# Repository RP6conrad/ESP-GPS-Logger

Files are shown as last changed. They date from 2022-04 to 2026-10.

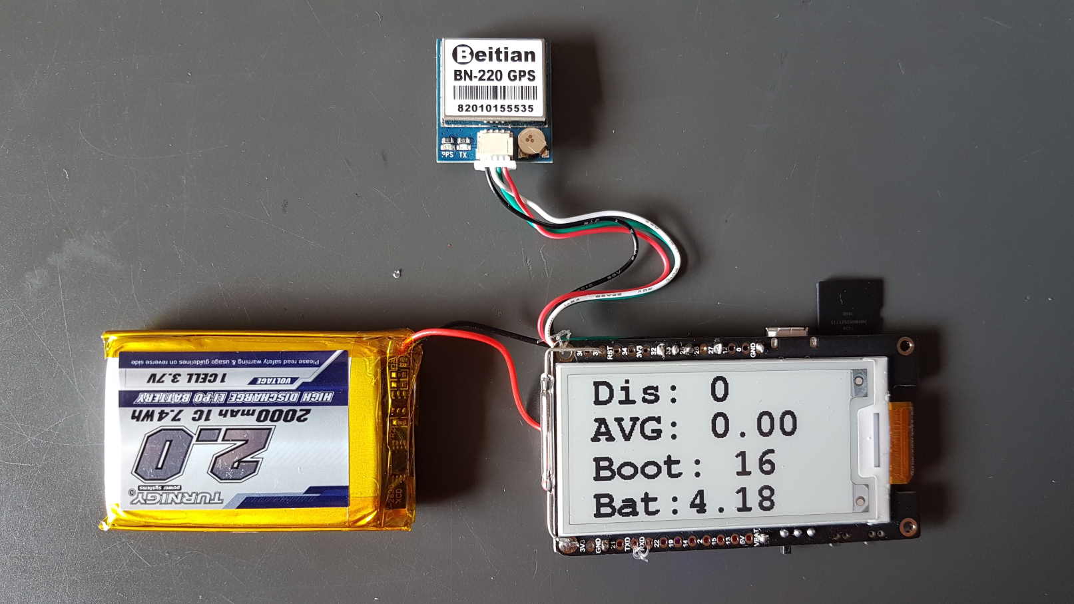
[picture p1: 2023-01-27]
Doc/ESP-naked.jpg

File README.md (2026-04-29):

# ESP-GPS logger

GPS logger for Speedsurfing, based on ESP32 & Ublox  hardware.  This is a open source project for a gps-speedlogger with a ESP32 µ-controller. This logger is approved for uploading to [http://gps-speedsurfing.com](http://gps-speedsurfing.com)
ESP GPS banner 1024x500

#### Hardware :
- e-paper display with build in ESP32 and micro SD-card(lilygo ttgo T5).
- A gps module ublox M8n / M9 / M10 is connected over serial. 
- A 2000 mAh protected lipo (103450) 
- Inductive charging coil
- Watersealed housing, electrical box or GoPro housing
#### Software
- GPS is configured for sending ubx navpvt (+navdop + navsat) messages. 
- Log rate can be 1,2,4,10 or 20 Hz (20Hz only with ublox M9). 
- Every message is logged to the sd-card. 
- Logfile type configurable : .ubx, .sbp, .gpy, .gpx, .txt. 
- gpy is the new compact open source format, developed for speedsurfing and is accepted @ gp3s.
- For speedsurfing, next values are measured and visible on the e-paper : 
	- Max speed average over 2s.
	- Max speed average over 10s.
	- 5*10s average from 5 runs.
	- Average speed over 100m, 200m, 500m, 1852 m (nautical mile)
	- Highest average over 30 min / 60 min. t
  - Alfa gate & exit live : after a jibe you see the actual "lost heigth" and "predicted lost heigth" (should be < 50m) !
	- Total distance from the session.
GPS_hardware1	
#### Interface
SW is written in Arduino IDE (C++). For easy access to the files on the sd, a ftp-server over wifi is integrated. Also OTA (over the air update) of the sw is possible. SW 5.58 : Thanks to the contribution of tritondm, the webserver is now extended and all files on the sd can be downloaded over this webserver. Also the complete configuration can be changed over the webserver !! No need for ftp anymore, but this is still possible. SW 5.75 : Autodetection Ublox M8,M9,M10 is supported. First time @boot, the type of ublox and baudrate is detected and stored in eeprom memory.
#### Arduino / library versions : 
- Arduino IDE 2.02
- ESP32 version 1.06, but next file need a change : 
- Change next file for compiling with Arduino IDE 2.02 (SD(esp32) to SD) C:\Users\andre\AppData\Local\Arduino15\packages\esp32\hardware\esp32\1.0.6\libraries\SD\library.properties
- ArduinoJson version 6.17.2
##### Building manual / first flashing :
https://docs.google.com/document/d/1XJD6BV1Xay4nXo0cDuo_IOtxC_f1LyG7DE7X6KGlAB0/edit?usp=sharing
##### Quick User guide
https://docs.google.com/document/d/1KfDua0H2_-J25e4L3CR8Znd8aIM6bbTPa6EjC0b7B3U/edit?usp=sharing
##### User manual :
https://docs.google.com/document/d/1j86kj3bNMID3sHCRT7QTYyrL7IHeQnGPec1LajsDfB4/edit?usp=sharing

##### A help for installing the first SW on the T5 board (written by Tobias, Arduino IDE) :
https://docs.google.com/document/d/1jIxAyi6wQ-Z860W548Xg--x6Ld8MBHJh7SCCWhSgnAs/edit?usp=sharing
##### Youtube : Information about the needed parts ! 
https://www.youtube.com/watch?v=kbG9EsX_yYk
##### Youtube : How to flash the T5 board en set the configuration !
https://youtu.be/902EDgWqitQ
##### Youtube : Importance of shielding the lipo from inductive charging
https://www.youtube.com/watch?v=GsCrqhh-bEE&t=22s
##### Youtube : PMMA casing and 3D print design with Onshape
https://www.youtube.com/watch?v=7HcuSVd9kAE
##### Youtube : ESP-GPS soldering and assembling (PMMA /3D print casing)
https://www.youtube.com/watch?v=2NX2z1mguc8&t=4s

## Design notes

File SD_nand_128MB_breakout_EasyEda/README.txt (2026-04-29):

<p>Breakout PCB for SDnand IC which fits on the T5 Lilygo E-paper. This as a replacement for the SD card, which takes extra space beyond the outline of the board. The preferred PCB thickness was 0.8 mm. The SDnand was the 128 MB version, which gives more then enough storage for the ESP-GPS project.</p>            
How to use：

At editor, open the document via: Top menu - File - Open - EasyEDA... , and select the json file, then open it at the editor, you can save it into a project.

如何使用：

打开编辑器，通过：顶部菜单 - 文件 - 打开 - 立创EDA... ，选择 json 文件打开在编辑器，你可以保存文档进工程里面。

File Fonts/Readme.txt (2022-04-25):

Copy files in 
//C:\Users\nlv05901\Documents\Arduino\libraries\GxFont_GFX_TFT_eSPI-master\Fonts\Custom
//C:\Users\nlv05901\Documents\Arduino\libraries\Adafruit_GFX_Library\Fonts
C:\Users\nlv05901\Documents\Arduino\libraries\GxFont_GFX_TFT_eSPI-master\Fonts\GFXFF

C:\Users\nlv05901\Documents\Arduino\libraries\GxEPD-master\src\GxFont_GFX.h
// select the library/libraries to add, none to preserve code space
//#include "U8g2_for_Adafruit_GFX.h"
//#include <Adafruit_ftGFX.h>
#include <GxFont_GFX_TFT_eSPI.h>

Declare in User_Custom_Fonts.h
  #include <Fonts/Custom/Sea_Dog_2001_Italic12pt7b.h> // CF SD1p12
  #include <Fonts/Custom/Sea_Dog_2001_Italic16pt7b.h> // CF SD1p16
  #include <Fonts/Custom/Sea_Dog_2001_Italic20pt7b.h> // CF SD1p20
  #include <Fonts/Custom/SF_Distant_Galaxy12pt7b.h>   // CF SD2p12
  #include <Fonts/Custom/SF_Distant_Galaxy16pt7b.h>   // CF SD2p16
  #include <Fonts/Custom/SF_Distant_Galaxy20pt7b.h>   // CF SD2p20
  #include <Fonts/Custom/SPINC___12pt7b.h>            // CF SD3p12
  #include <Fonts/Custom/SPINC___16pt7b.h>            // CF SD3p16
  #include <Fonts/Custom/SPINC___20pt7b.h>            // CF SD3p20
...
#define SD1p12  &Sea_Dog_2001_Italic12pt7b
#define SD1p16  &Sea_Dog_2001_Italic16pt7b
#define SD1p20  &Sea_Dog_2001_Italic20pt7b
#define SD2p12  &SF_Distant_Galaxy12pt7b
#define SD2p16  &SF_Distant_Galaxy16pt7b
#define SD2p20  &SF_Distant_Galaxy20pt7b
#define SD3p12  &SPINC___12pt7b.h
#define SD3p16  &SPINC___16pt7b.h
#define SD3p20  &SPINC___20pt7b.h

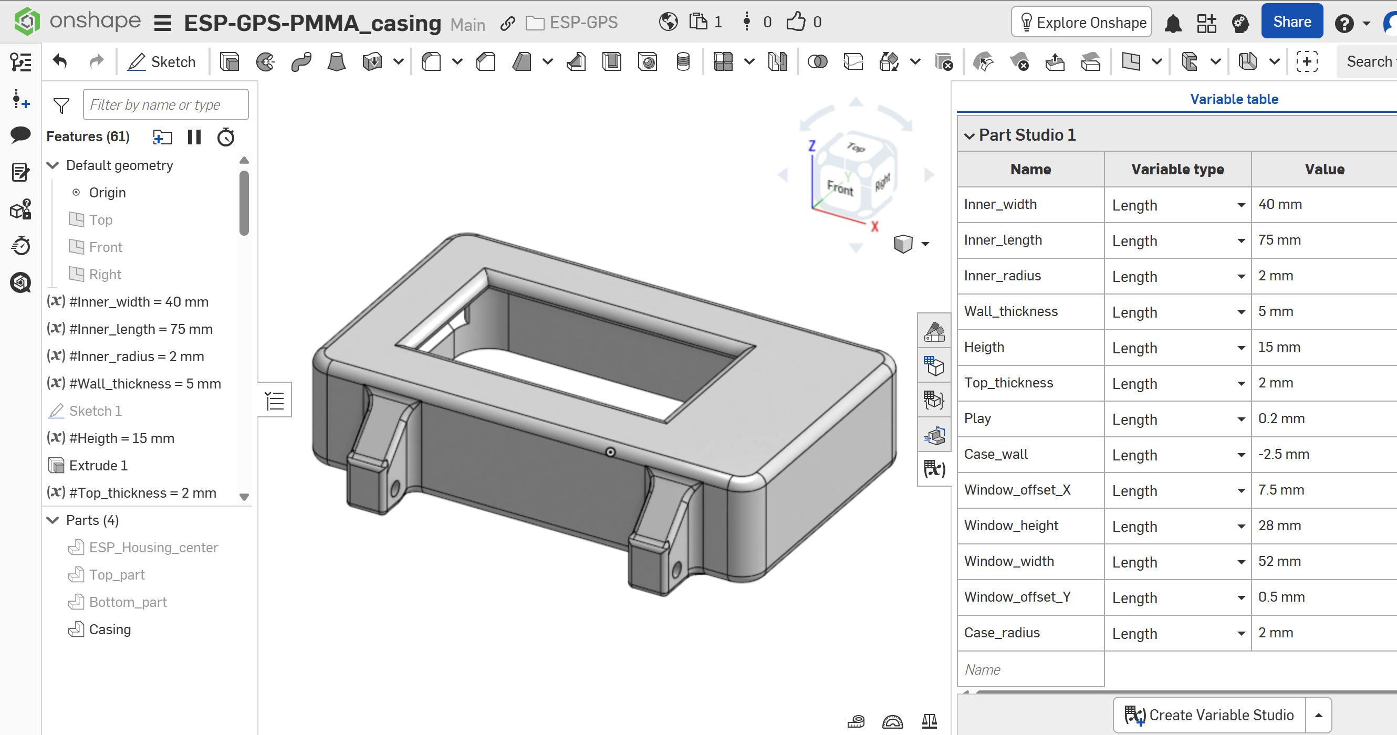
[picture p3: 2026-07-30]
3D_housing/Onshape_variables_gps_casing.png

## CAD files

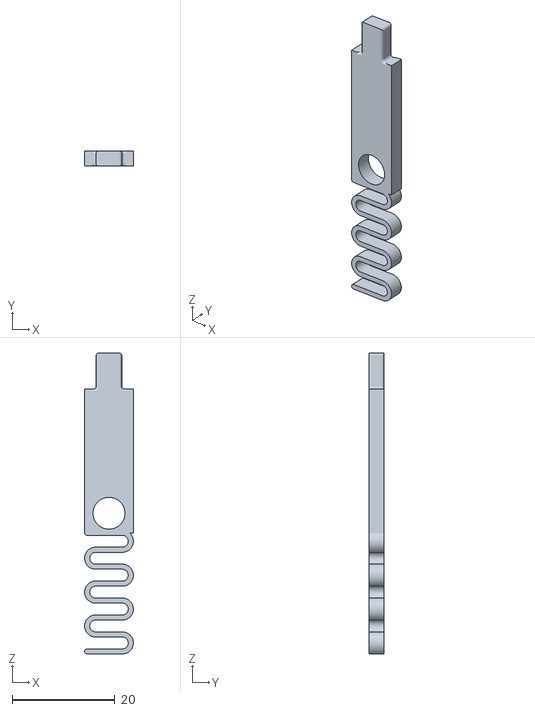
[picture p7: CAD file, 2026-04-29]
3D_housing/Magnet_spring.stl
9.50 x 3.00 x 58.6

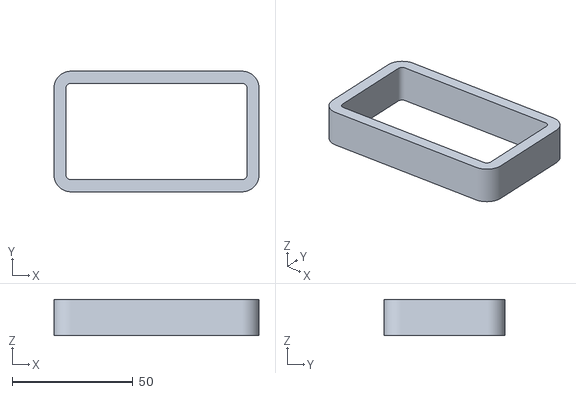
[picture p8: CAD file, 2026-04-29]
3D_housing/ESP-GPS_PMMA_housing.stl
85.0 x 50.0 x 15.0

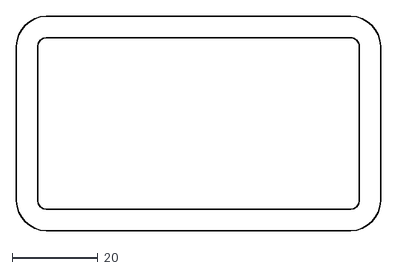
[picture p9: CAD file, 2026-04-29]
3D_housing/ESP_Housing_center_2D.dxf
85.0 x 50.0

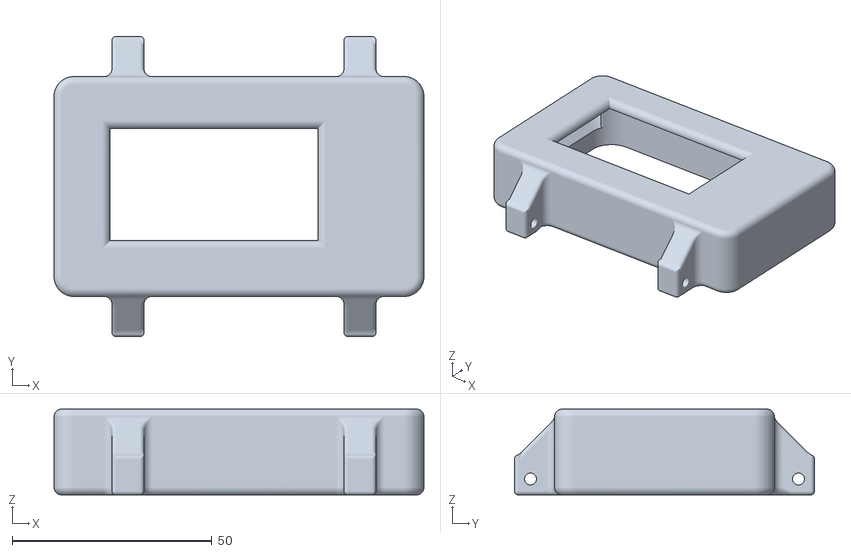
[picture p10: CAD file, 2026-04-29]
3D_housing/ESP-GPS_3D_case.stl
92.5 x 75.0 x 21.5

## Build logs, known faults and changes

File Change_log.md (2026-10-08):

### Changes SW 7.0c
* Added actual partition size in firmware webpage
* Bugfix naming &.gpy -> $.gpy
* Bugfix calibration bat in configuration (was stuck on 1.83)
* Watchdog now default functions
* infobar removed vor statscreen F and G (top5 100m / NM)
### Changes SW 7.0beta
* Added auto-upload to speedsurf.app. If wlan connected, al *$.gpy files are uploaded to speedsurf if api key is present
* api key is stored in preferences.h
* gpio12 is now ouput for screen T5 Version 2.4
* New partition table with 1.9MB app, needed for https uploading
* New gpy files are ending with $.gpy, after uploading name changes to *.gpy
* Added compile macro AUTO_UPLOAD_SPEEDSURF (Definitions.h) for compiling without auto upload : bin still fitts in the old partition then
* With auto-upload : Sketch uses 1376406 bytes (65%) of program storage space. Maximum is 2097152 bytes.
* Without auto-upload : Sketch uses 1212586 bytes (92%) of program storage space. Maximum is 1310720 bytes.
### Changes SW 6.05h
* Added setting for screen T5 version 2.4 = gpio12 as output, setting high for screen on !
* Bugfix setting knots / km/h in the OTA_html.h (no == with floats !!!)
* Bugfix statscreen 7 : no negative bars
* Added statscreens for Salvador F,G,H,I,J
* Added sleepscreen 3 for Salvador
* Bugfix screen orientation
* Removed "M10 Full power"
### Changes SW 6.05g
* bugfix screen 6 / shut down screen
* Added maxSVS in config, to limit nr of sats in nav solution. This for "lost points" prevention
* GPS nerd settings button in configuration webpageto hide all detailed gps settings
* p1/p2 data type in json is now string, so all digits stay unchanged
* check for string type p1/p2, other wise panic when still double type !!!
* Auto track setting when p1/p2 is zero in the config : first 500m run with speed min 5 m/s after 600 m run distance
### Changes SW 6.05delta
* settings M10 added tot .txt file
* full power mode in the config
* Added setting M10 minimal elevation satellite above horizon, 5 - 25 degrees
* Stat-screen D  5-9 track speed, update Top_5()
* Stat-screen E Ranking Nautical mile screen 
* Stat-screen F Ranking 100m screen 
* track_speed Start -> finish now with exact doppler - distance
* added projected doppler speed to track speed (only in stat screen now)
* json buffer now 2048 bytes (was 1536)
* Screen orientation now in config, had to update GXDEM0213B74 lib, and bugfix for screen offset (added VISIBLE_WIDTH 122)
### Changes SW 6.05beta
* Added max nr of satellites in config (motion has a fix limit of 18)
* Added "track-speed" measurement between 2 gps points, start and finishline perpendicular to start / finish point
* Added stat-screen B with distance to start line, gps distance track, track-speed and doppler speed.
* Added speed-screen F with distance to start line and track seconds passed
* Best 5 track runs are added to *.txt file (track speed and doppler speed, but doppler is for 250m (track distance<350m) or 500m.
* Added SD-nand breakout files to github (easy eda format)
* Added 3D housing files to github (stl + dxf for lasercutting)
* GPST post 1h knots bugfix
* added  #define SDMMC_FREQ_DEFAULT
###Changes SW6.01c
Added E-paper type to SW version
Bugfix speedscreen 6, max_display_speed
Add speedscreen A, with CM = 2s max run and TM = 2s max session
Logtime left prevent divide by 0 is al logfiles are switched off
###Changes SW6.01a
Bugfix calculation AVG 5*10s !
###Changes SW6.01
* Added sign to Dist point to line ()
* Added GPIO19 for switch to AP-mode
* New run detection after stop delayed until speed > 4 m/s
* Statscreens can be switched by GPIO39 short push if Stat screen time is set to 0. No speed screen choice then with GPIO39 short push !
###Changes SW6.00
* M10 set permanent to high nav rate possible, at the cost of a higher current draw (+5mA...) (Irreversible !)
* Added SD_MMC write/read speed, file test.txt of 1MB is used for this
* Speed measuring SD card, file test.txt 1MB used for measurement, results saved in file.txt
* Added shutdown_voltage to config : if set to 0, you can force a powercycle by draining the lipo !
* Added warning in webserver as shutdown_voltage in config  < 3.0 V
* min cpu freq = 80MHz, is needed for SD_MMC
* boot @ 240 MHz, as SD_MMC need min 80 MHz
* SD in SD_MMC 1bit mode, this is the hardware SDIO bus from the ESP32. Only with dedicated pins possible. 
* As the sd card only wil reset after powerdown, a powercycle is necessary for SPI-mode -> MMC-mode !
* Proposal from Alhop for the SD NAND cards : SD_MMC 1 bit instead SD over SPI
* Pullup needed on pin 2 before begin.SD_MMC needed for some cards
* Pullup in deepsleep on pin 2 for minimize leakage current SD cards
* Bugfix for GPIO 12,19 and 39  init with pulldown/pullup
* Bugfix Logspace left calculation
###Changes SW5.91
* Added 115200 Baud for Beitian Bx122 
* Bugfix for M8@38400 bd
* Added estimated Logspace left (webserver+display). Calculates logtime with actual settings sample-rate, file selection and free space.
* GPIO 19 Go to sleep pin PULLDOWN. 
* GPIO 21 hold HIGH SIDE SWITCH 
* GPIO2 pulldown in deepsleep, was still floating
* Added statscreen B , last run, best run, slowest run and average
 ###Changes SW5.90beta
* Stat screen 500m / runs bugfix time reading : tim 18:6 -> 18:06
* Adapt FIR filter bat reading 0.1 -> 0.02, more consistent measurement
* Auto calibration, full lipo 4.2V -> 4.3 V
* Before Wifi start, min 3.4V
* Override lipo calibration possible, only auto-calibrate with more then 5% too high reading
* Deep sleep current -> 80 µA without SD, with SD 550 µA, this by deleting  "hold_gpio_enable()" !!!
* No config.txt -> 10s wifi search
 ###Changes SW5.89e
* Added Lisa logos
* Stat_screen 7,8,9 no info-bar, because info-bar overwrites last line....
* Shorten bar_length if actual time is visible 
* Added bar length info on the screen (large font on)
* Added speed_screen 7 -> 500m (Weymouth speed week!)
* Added stat_screen 8 -> Best 500m runs + timestamp.
* Added stat_screen A -> Best 2s runs + timestamp
* stat_screen / speed screen choice extended, digits + characters can be used.....
* Bugfix in simon screen : rounding error fix
 ###Changes SW5.88
* Added upload session to GPSTC 
* Added actual time in speed screen "Large Font Off"
* Added Lisa logos
* Stat_screen 9 no info-bar, because info-bar overwrites last line....
* Shorten bar_length if actual time is visible
 ###Changes SW5.87
* Timezone & DST bugs in gpy file correction
 ###Changes SW5.84
* stat6 screen bugfix "previous run", will be held until speed > 4m/s
* Support for daylight saving in several timezones, configurable. 
* Support for 2 SSID (can be used with smartphone hotspot)
* Bugfix in gpx file : first line start with <<, should be <
* Bugfix auto-detect gps
* Auto calibrate -> when charging in deepsleep, with every wake up(1800 s), ADC bat voltage is measured
* and highest value is stored in eeprom. With full charging, this should be the end voltage of the charge IC TP4056 (4.2 V)
* cal_bat in config.txt is only for info !!
* see https://lygte-info.dk/review/Review%20Charger%20TP4056%20UK.html
* Added bitmaps for FMX, ChallengerSails, Phantom, F4  (contribution Simon)
  ### Changes SW 5.83
* Cpu freq when SetupGPS() 240 MHz -> 40 mHz, Current with M10 87 mA -> 57 mA
* Cpg in webpage "Files" if CPU-freq is not optimal
* Checksum fail UBX message in error log
* Voltage battery in infobar
* First test : 5 Hz -> need 80 MHz, 10 Hz -> need 80 Mhz
* Add "Giant font ON" in speed screens
* Moved E_paper task to core 0
* RxBuffer Serial2 1024 -> 2048
  ### Changes SW 5.82
* Warning sample-rate setting moved to webserver index page (files)
* Moved Button_push class E_Paper -> ESP_functions.h
* BUFFER_SIZE 9500 -> 9000 due to ESP32 2.0x lib, to prevent "DRAM segment data does not fit."
* interrupt on GO_TO_SLEEP_GPIO for set Wifi_Search to 150 without delay
* Boot with Wifi station and acces point simultanous
* Added local storage if no SD card found, only 1.5 Mb, total flash is only 4 Mb !!!
* If in AP-mode, but counting down, shutdown is possible now.
* Added Storage space + bat voltage + Firmware version to webserver files page
* Added partitions.csv in the root dir, ESP32 V1.0 with 4MB flash
* If this file is in the sketch dir, it will be used instead of the Arduino Menu setting !!
  ### Changes SW5.81
* added drop down menu for Sail and Board logos  
* added board logos Carbon Art, Thommen, Bic
* added saillogo S2_Maui=11
* gpx.h changes for better fit to the standard (http -> https, indentations, stand alone, contribution from Michael G)
* removed limits for sample-rate 
* added warning after upload if the sample-rates are too high
* ShortPush39 50ms->10ms
  ### Changes SW5.80
* Extended choice for sample rate : add 4 Hz and 8 Hz  
* extended choices for GNSS 
** M10 4GNSS : GPS+GLONASS+GALILEO+BEIDOU, max 4Hz or lost points....
** M10 3GNSS : GPS+GALILEO+BEIDOU_B1C :  8Hz possible with no lost points (default = GPS+GALILEO+BEIDOU_B1L )
** M10 3GNSS : GPS+GALILEO+GLONASS, max 5Hz or lost points....
** M10 2GNSS : GPS+GLONASS or GPS+GALILEO : 10Hz possible with no lost points 
* Sample_rate limited in function of GNSS settings (M10)
* Wifi AP bug fixes
  ### Changes SW5.79
* Speed screen NM big font, 2 digits after dec. point
* Add file name option name_date_time_MAC
* Time out nav-pvt msg -> 10s, then trouble screen
* Check for nav-pvt msg after init gps, NOK -> then trouble screeen
  ### Changes SW5.78
* Sleeptime 21600s -> 1800s, only screen update if delta_bat_voltage> 0.01 V !!
* Wake-up without refresh screen < 50 ms, with refresh 2665 ms !!
* Start_logging_speed configurable over webserver
* Watchdog when downloading file now 600s
* Added actual 0.5h and actual 1h in speed screen with "big Font"
* Speed_screens can be choosen, analog to the stat_screens : setting 841 will toggle between three screens : 1,4 and 8. Only one digit : toggle from 0...9
* Especially usefull if you have the sealed pushbutton instead of the reed-switch

  ### Changes SW5.77 (mainly by avoprykk)
#### Fixed:
* OTA_Server firmware upload page javascript.
* GPS_Data changed BUFFER_SIZE from 10000 to 9500 as for fitting into 1.5M Image partition.
* Some compiler errors about types.
#### Changed:
* E_paper>
* Display unified row heights macros, changes in screens accordingly
* ESP-GPS logo size to 24x24
* Moved time, gps and battery for all screens to bottom row infobar.
* New screen for GPS initialization.
main.cpp> Ublox initialization moved after Wifi connections closed.
#### New:
* Partial code for OTA autoupload, dev status yet.
M9 15Hz support
* Added support to PlatformIO and partially for ESP-IDF (CMakefile.txt), thats why Rtos.ino moved to main.cpp. Wrapper module: https://github.com/aivoprykk/ESP-GPS-Wrapper
* Filename Rtos.h -> Definitions.h
* Added ESP_functions.h with general functions
* Bugfix Short_push for speed_field choice
* Added field 9 : Run-AVG, Alfa, NM, 1 hour
* Bugfix bat%@boot

   ### Changes  SW 5.0
*   Automatic ### switching to portable with overspeed (>20 m/s)
*   Extra dynamic model Automotive : 2-> automotive
*   for higher accuracy, change of datatypes to double
*   All speeds are now in mm/s (format double)
*   Added STATS3 screen with M100/M500, config.Stat_screens 6
*   Added Definitions.h for general #define
*   Bugfix in new_run_detection, speed m/s -> mm/s
*   Start logging if speed>MIN_SPEED_START_LOGGING, now 2m/s
*   Added log files in oao format
*   Removed logging to csv files
   ### Changes  SW 5.1
*   Add distance of run
*   Add configurable bar in "speed" screen, reflects run_distance, default 1852m = full bar
   ### Changes  SW 5.2
*   Change to proportional font 12pt and 18pt, speed screen now has 2 variables on top
*   Replace sat nr in speed screen with other variable
*   Add a alfa indicator, the actual distance from the start point is shown, has to be < 50m
*   At the same time shows the bar the alfa distance, 250 m = full bar
*   If config.field=1: 
*          automatic switching to alfa screen after jibe until 300 m 
*          then Run /. AVG screen.
*   If config.field=2:        
*          if run distance>1852 m, switch to NM view
*          else  Run screen !!       
   ### Changes  SW 5.3       
*   No "window" anymore for alfa, needs further development
*   Some display ### Changes
*   This version goes to GP3S
   ### Changes  SW 5.4
*   Wifi stays on for 100s, first 10s searching for SSID, then still 90s AP actif if reed switch seen.
*   Station or AP, but not both at the same time !
*   Wifi screen stays as long as connection SSID or AP, no SAT nr in Wifi screen as GPS is not read
*   Changed esp32 lib from 1.0.4 to 1.0.6
   ### Changes to ESP32FTP lib, so Android FTP is now possible
*   FTP status visible in Wifi screen, FTP = 2 : waiting for connection, FTP 5 : Connection OK
   ### Changes  SW 5.42
*   Removed CR in FTP lib for directory listing, as FTP has a problem with MacOS
   ### Changes  SW 5.44
*   Several ### Changes in FTP lib for problem with MacOS
*   Bugfix for e-paper lib BN74
*   Optimization Alfa screen, Window...
*   Test for 1.54" e-paper
   ### Changes  SW 5.45
*   exit distance for alfa = estimation of alfa-circle with current heading
   ### Changes  SW 5.46
*   GPIO 25/26 are RTC, drive capability changed!! Were not working !!
*   extra Button GPIO_Pin12, pullup, give STAT4 screen !!
*   long push GPIO_Pin12 reset STAT4 screen
*   short push toggles next screen
   ### Changes  SW 5.47
*   NM bar start@minimal speed (10 m/s ?)
*   More stats screen over GPIO pin 12
*   Alfa speed screen with Window, avg speed 250m and Exit
*   Sea model does not give a gps-fix if actual height is not on sea-level, default = 0 !!!
*   wifi off screen nr of sats added
*   bugfix bat symbol if bat_voltage>4.2
*   Choice of stat_screens extended : preferred screens are chosen with their nr : Stat_screens = 523 is then stat_screen 5, 2 and 3 !!!
   ### Changes  SW 5.48
*   Added Simon screens
*   RTC offset for sleep screen 
*   RTC txt for sleep screen
*   sleep_screen "speed in km/h" or "knots" depends on calibration
*   nr of stat screens are changed (e_paper.h)
*   low_bat voltage 3.1 -> go to sleep !!!
*   update STAT4 with actual run, added extra display_speed[]
*   choice GPIO12 screens with config
*   choice Logos with config
*   choice sleep-screen, off-screen with config
*   json doc 512 -> 1024 byte
*   boot screen added config fail / ok
   ### Changes SW 5.49
*   Alfa calculation , alfa-circle² to avoid sqrt in calculations, factor 111120 -> 111195
*   Bugfix in alfa calculation (pointer + 1)
*   Shutdown : RTC data only written if new GPS-data is available
   ### Changes SW 5.50
*   Added bar graph screen which shows the speed from al the runs (max=42)
*   Scale  bar value depends on fastest run, min value = 24
*   Speed km/h or knots
   ### Changes SW 5.51
*   new run detection, min speed of 5 m/s
*   max nr of stat screens change to 9
*   bugfix Log_to_SD() before set speed to 0 with bad reception, checksum ubx was not correct with speed 0 !!!
*   Added config.gnss : set for 3 gnss possible, works only with ublox ROM 3.0 !
*   Check for GNSS setting : ubx msg MON_GNSS
*   Add setting GNSS in txt file @ end of session
   ### Changes SW 5.52
*   bugfix for bar graph 
   ### Changes SW 5.53
*   bugfix for filenaming if logUBX=0 !!!
   ### Changes SW 5.54
*   Added extra Board / Sail logo's, design by Hans Scholten
*   Added variable to config.txt : "stat_speed":2,  // speed less then 2 m/s -> stat screens
*   Filenr depends now from existing .txt files !!
*   Shut down screen : add type of E-paper (in case you forgot...)
*   Webserver can now download and delete files from the SD-card !!! 
*   Contribution from Triton_dm on github !!
   ### Changes SW5.55
*   Bugfix for choice screens with GPIO39 after boot
   ### Changes SW5.56 (Contribution from Triton_dm on github !!)
*   Added an upload section to the webserver
*   Enabled the webserver on AP Usage, prevent from stopping during downloading files
*   Add IP Address of the AP to display
*   Add a special LOGO section > 99 and add a special logo of a beer supplier hier @Achensee/Tirol
*   Change the Webinterface to a responsive design
*   prevent delete on one click
   ### Changes SW5.57 (JH)
*   Added file timestamp to webserver !!
   ### Changes SW5.58 ### Changes by tritondm !!
*   fix the download issue with phps extionsion on android chrome
*   add a config section for changing config - thats the base for the next step - config credentials for gps-speedsurfing.com and upload
*   after before upload a config_backup will created
   ### Changes SW5.60 Bugfixes + added sbp file format
*   Changed next file for compiling with Arduino IDE 2.02 (SD(esp32) to SD)
*   C:\Users\andre\AppData\Local\Arduino15\packages\esp32\hardware\esp32\1.0.6\libraries\SD\library.properties
*   Bugfix decoding config logo, GPIO12 and stat_screen
*   Range bar_length now from 100 - 10000
*   Removed fileformat .oao
*   Added new fileformat .sbp
   ### Changes SW5.61 First draft new open source fileformat
*   Some minor ### Changes for the webserver (triton_dm)
*   Separate Board_logo and Sail_logo config
*   Test with other fonts in speed screen, added "speed_large_font" to the config : Run, Alfa and NM can have a bigger font.
*   Changed order config.field, 1=Auto between Run, Alfa & NM, 2=Run & NM, 3=Alfa, 4=NM, 5= Total distance, 6= 2s/10s, 7= 0.5h, 8= 1h
*   Font 46pt_nr and 84pt_nr added, condensed format only digits and decimal point to save memory 
*   Added Github link to main menu
   ### Changes SW5.62
*   Added GPX file format
*   Added GPY file format
*   If no config file : Wifi AP waiting time = 120 s
*   Bugfix config webserver : no switching to km/h if knots was set
   ### Changes SW5.63
*   Added support for BN266 e-paper
*   Changed GPS-parser union to struct, every ubx message has its own struct now
*   Added ubx nav dop Msg for extracting HDOP
*   Added ubx mon ver Msf for extracting sw / hw version ublox
*   Changed baudrate ublox to 38400, necessary for 10Hz navDOP + navPVTD
*   Correction timestamp list files with FTP 
*   Added sail logo "Severne" = 10
*   Added board logo "F2" = 10
*   Bugfix for SSID with white space
*   Added watchtdog for WAKE UP screen (hangs sometimes after OTA)
*   Added loadbalance for flushfiles()
   ### Changes SW5.64
*   Bugfix garbage frame in gpy / ubx
*   Reboot ESP : ublox_off for 1s !!
*   Added support for ublox M10 (Mateksys maxM10s), define in Rtos.h
*   Time stat screen toggle configurable
*   bdrate back to 19200BD, should be ok for 10100 (nav_pvt) + 1026 bytes(nav_dop)
*   Added support for GNSS GPS + GALILEO + BEIDOU for M8 + M10
*   Correction time on sleep-screen with timezone
   ### Changes SW5.65
*   Bugfix stat screen time
   ### Changes SW 5.66
*   Added sw-version + e-paper type to Wifi-on screen + sleep screen Simon
*   baud rate back to 38400 for nav sat msg
*   Added (configurable) ubx nav sat message to ubx file, Rate = 1/10 of NAV PVT, timeshift 18.05 s for ascending order ubx msg
*   This is if you  want to evaluate the signal quality of your gps (ucenter)
*   Filename with Timestamp in it, configurable
*   .sbp file corrections, problem with uploading to gp3s, header change (0xa0, 0xa2)
*   .sbp file correction for sAcc, hDOP
*   added alfa screen to 0.5h / 1h, bar_length gives time passed 30min /60 min
*   sleep_screen Simon : 500m -> 1h best
   ### Changes SW 5.67
*   NAV SAT not with polling, but over cfg msg @ 10% rate of NAV PVT
*   NAV SAT for M10 added @ 10% rate of NAV PVT
*   removed timeshift iTow NAV SAT
*   Added extra option filenaming
*   Some ### Changes to header SBP
*   correction time bug in sleep screen
*   reset 30 min / 60 min bar if speed drops<2m/s for 120s (screen best 0.5h / 1h)
   ### Changes SW 5.68
*   Analog bat measurement to function()
*   ESP32 time is now local time, min 5 sats visible !!
*   Add check for nav pvt valid flags time&date before setting the time (thanks Peter!)
*   Check for plausible year when GPS time is set (>=2023)
*   Removed timelib.h, only sys.time.h needed
*   Fix time_bug in different screens
*   Add Ubx ID M8(ROM3 necessary,5 byte ID), saved in error.txt 
*   Add Ubx ID M10(6 byte ID), saved in error.txt 
*   Add Class GPS_NAV_INFO + Evaluation last 16 NAV_SAT msg in log file error.txt
*   Add navDOP msg to ubx file, if nav_Sat is active (for analysing data) 
   ### Changes SW 5.69
*   Change baudrate for M10 to 38400 bd, #define ALI_M10 in rtos5.h
*   Bugfix for gpy file : MakeTime -> mktime, offset from 1970 -> 1900, month -1 !!!
*   Option for other wake-up GPIO with #define in rtos5.h
*   Add type e-paper to .txt file
*   Some text in e-paper adapted : Mile ->NM, Alf->Alph, Dis->Dist
   ### Changes SW 5.70
*   Again timebug -> e-paper keyword "now" may not be used for getLocalTime() !!
*   Same issue in SD_card.cpp -> open files !!
*   GPS_SAT_INFO buffer 16 -> 10
*   Set GPS_time @ start logging
*   check for year>2023
*   While waiting for Sats / Min speed : Wifi Off with waiting Sats/Speed on screen
*   Total time in .Txt from start logging
   ### Changes SW 5.71
*   Again bugfix for time in gpy file (offset year 1970->1900, month->-1)
*   Removed #include timelib.h
*   Removed listing of directorys in webserver
*   Add sortTable() after DOM is loaded : now the files are ordered by date after loading all filenames !
*   Timestamp files with FTP command MLSD is now UTC
*   Add type of ublox to .txt file + e-paper shut down
*   https://www.mischianti.org/2021/03/28/how-to-use-sd-card-with-esp32-2/
   ### Changes SW5.72
*   .txt files configurable over webserver, if name_MAC_counter, .txt file is necessary for keeping track counter !!!
*   When Wifi, NTP time is set, if needed, directory "Archive" is created
*   When webserver start, Files older then xx days are copied to directory "Archive", are not visble in the listing anymore.
*   Added link "Archive files" in header : to move files to the Archive dir when older then archive_days
*   Added link "Archive list" in header : to list all the files on the SD, dir "Archive" included
*   Link to overview Board / Sail logo updated
*   STAT1 screen Sat -> last 2s, 3m/s for new value needed
*   STAT6 screen Mile -> NM
*   Sleep screen bat voltage -> bat percent, 4.2=100%, 3.4=0% 
   ### Changes SW5.73
*   Bugfix name ublox M10 38400bd in off screen
*   Downloading _filename bugfix, no underscore
*   timezone changed from int -> float for partial timezones, drop down menu choice  !!
*   Speed screen 5 -> distance always km/h, run -> bat symbol 
*   Added auto detection ublox type M8 / M10 and 9600bd/38400 bd
   ### Changes SW5.74
*   Debouncing reed switch with 200ms @boot
*   Shutdown screen 10s -> 5s
*   Bat voltage calibration min value 1.7 -> 1.6
*   Bugfix GPIO12 screens 
*   Changed default settings when no config.txt
*   Add watchtdog to task0 + task1 separat, Time out = 60 s
*   Changed order Wifi screen, so IP is not in the middle anymore
*   Check bat voltage@boot, if too low back to sleep. This to prevent a bootloop 
  ### Changes SW5.75
* Bugfix time format gpx files
* Added future fly logo (basti)
* Bugfix .txt file M8/M10 serial nr
* Added TROUBLE screen if no ubx message for longer then 2000 ms 
* Added SPEED2 screen with giant Font (Simon Design)
* filesizes always in MB
* override watchtdog_task0 when downloading (large) files
* Added SD Free space Mb in Boot screen
* Boot screens changes by Simon, ESP-GPS logo added 
* Added actual SW version & Type of e-paper to Firmware page
 ### Changes SW5.76
* Sleeptime 3000s -> 21600s
* nav_sat timeout 2000 ms -> 4000 ms
* add 1h to speed screen, setting 9
* bugfix wifiAP screen : name SoftAP
* shutdown screen : Saving your session or Go back to sleep
* Autodetect GPS only once, then saved in EEPROM
* Can be changed over the webserver (configuration), only set AUTODETECT again !
* Added support for the ublox M9 (Beitian BK180), logging@20Hz + 4 gnss simultan

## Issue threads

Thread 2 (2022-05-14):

File naming

prichterich, 2022-05-14:
I suggest to change the naming of the log files to include the date (preferably at the front, and in yyyy-mm-dd format), and possibly also the time (add <space or underscore>hhmm).
In theory, the date and time file stamps on the files could be used, but in practice, transferring the files with FTP time stamps the transferred files with the date and time of transfer, so the original dates and times are lost.

To prevent file names from getting very long, but to keep information about the units used, the MAC address can be shortened to the last 4 digits in the file names. The first 8 characters of the MAC address tend to be identical or almost identical for ESP units, so they add very little information.

RP6conrad, 2022-05-14:
With WinSCP (FTP client for Windows), the correct date/time stamps are transferred, but maybe other FTP clients behave different.

Greetings, Jan.

Verzonden vanuit Mail voor Windows

Van: prichterich
Verzonden: zaterdag 14 mei 2022 15:46
Aan: RP6conrad/ESP-GPS-Logger
CC: Subscribed
Onderwerp: [RP6conrad/ESP-GPS-Logger] File naming (Issue #2)

I suggest to change the naming of the log files to include the date (preferably at the front, and in yyyy-mm-dd format), and possibly also the time (add hhmm).
In theory, the date and time file stamps on the files could be used, but in practice, transferring the files with FTP time stamps the transferred files with the date and time of transfer, so the original dates and times are lost.
To prevent file names from getting very long, but to keep information about the units used, the MAC address can be shortened to the last 4 digits in the file names. The first 8 characters of the MAC address tend to be identical or almost identical for ESP units, so they add very little information.
—
Reply to this email directly, view it on GitHub, or unsubscribe.
You are receiving this because you are subscribed to this thread.Message ID: ***@***.***>

prichterich, 2022-05-14:
I just double-checked, and FileZilla on macOS sets both creation and modification date of the file to the transfer date. FileZilla is also the only ftp program that seems to work (I've tried 3 or 4 others). Of the speedsurfers I know in the US and Australia, a lot are Mac users.

jetsoftwind, 2022-08-21:
I use filezilla on windows and as long as the menu option - Transfer/"Preserve timeStamps of transferred files" is on then the modifed  date/times are correct the created time is the transfer time. On windows the shortcut key is Ctrl-U

Rolzzz, 2023-01-02:
just bumping this one, I'm using new method of pulling down from internal web browser and file format when downloading is as follows

_Rolz_94B555C8DB1C_000.ubx
_Rolz_94B555C8DB1C_001.ubx
_Rolz_94B555C8DB1C_002.ubx

if I download and then delete from device it creates a new file that again starts from _Rolz_94B555C8DB1C_000.ubx
then if I try to save to my gps file location on my computer I get message file already exists.
if file name could include date that would be awesome. :)

Closed 2023-01-18.

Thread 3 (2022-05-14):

Incorrect checksums

prichterich, 2022-05-14:
The current code writes NAV-PVT sentences with incorrect checksums for points that are filtered (the speed is set to 0 because of fewer than 5 satellites, sAcc > 1m/s, or speed >40 m/s). These sentences are then rejected by readers that check the checksum, which includes u-center and GPS Speedreader.

The cause is that the filtering is done before writing the sentences to log files. The problem could very simply be fixed by first writing the data to the log file, and then applying the filters. The filters make sense for internal speed calculations, but the log files should contain the original information from the GPS chip, not data that have been altered in any way by the firmware.

RP6conrad, 2022-05-14:
Yes, this has to be corrected. I’ll change it with the next update.

Greetings Jan.

Verzonden vanuit Mail voor Windows

Van: prichterich
Verzonden: zaterdag 14 mei 2022 15:51
Aan: RP6conrad/ESP-GPS-Logger
CC: Subscribed
Onderwerp: [RP6conrad/ESP-GPS-Logger] Incorrect checksums (Issue #3)

The current code writes NAV-PVT sentences with incorrect checksums for points that are filtered (the speed is set to 0 because of fewer than 5 satellites, sAcc > 1m/s, or speed >40 m/s). These sentences are then rejected by readers that check the checksum, which includes u-center and GPS Speedreader.
The cause is that the filtering is done before writing the sentences to log files. The problem could very simply be fixed by first writing the data to the log file, and then applying the filters. The filters make sense for internal speed calculations, but the log files should contain the original information from the GPS chip, not data that have been altered in any way by the firmware.
—
Reply to this email directly, view it on GitHub, or unsubscribe.
You are receiving this because you are subscribed to this thread.Message ID: ***@***.***>

Closed 2023-01-18.

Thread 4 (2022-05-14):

Support logging using 3 GNSS systems

prichterich, 2022-05-14:
The current firmware version does not set which GNSS systems are used, so the default (GPS + GLONASS) is used. User can pre-configure GPS chips (other than the BN180) to use other systems using u-center, but that requires extra equipment (FTDI cable) and skills (using u-center).

I propose to add config flags to use additional GPS systems, in particular Galileo. The BN220, 280, and 880 chips all can handle 3 systems at 5 Hz without problems, and _probably_ also at 10 Hz (I usually use 5 Hz, but I think decrepit uses 10 Hz with his prototypes).

The general thinking is tracking satellites from 3 systems gives higher accuracy than from 2 systems. The benefits may be small in situations where reception is excellent and 18+ GPS+GLONASS satellites can be tracked, but a reduction in reported error estimates can still be seen.

I have added a config flags and the necessary config sentences in my code, but only for Galileo. I have not checked in the changes to my fork on Github yet because there are still some open questions:
1. What should be the default - 2 or 3 GNSS systems?
2. Should BeiDou also be supported (as an alternative to Galileo)?

Regarding BeiDou: in my tests with different BN chips, I found that they do not all support BeiDou, even if they report the same firmware version (3.0.1). One chip ignores setting BeiDou on completely, another chip seems to accept the setting.  It would be interesting to hear about other chips. I also do not have any data if adding BeiDou improves accuracy.

RP6conrad, 2022-10-11:
Can you give me the settings in U-center for 3 different GNSS (see prontscreen) ?
I have several Beitian BN GPS which have still ROM version 2, these do not support Gallileo.
I prefer to have default 2 GNSS, and configurable 3. I prefer Galileo, but I have no experience with 3 GNSS settings. Maybe with ROM version 2 only Beidou is possible.

Greetings, Jan.
Verzonden vanuit Mail voor Windows

Van: prichterich
Verzonden: zaterdag 14 mei 2022 16:08
Aan: RP6conrad/ESP-GPS-Logger
CC: Subscribed
Onderwerp: [RP6conrad/ESP-GPS-Logger] Support logging using 3 GNSS systems(Issue #4)

The current firmware version does not set which GNSS systems are used, so the default (GPS + GLONASS) is used. User can pre-configure GPS chips (other than the BN180) to use other systems using u-center, but that requires extra equipment (FTDI cable) and skills (using u-center).
I propose to add config flags to use additional GPS systems, in particular Galileo. The BN220, 280, and 880 chips all can handle 3 systems at 5 Hz without problems, and probably also at 10 Hz (I usually use 5 Hz, but I think decrepit uses 10 Hz with his prototypes).
The general thinking is tracking satellites from 3 systems gives higher accuracy than from 2 systems. The benefits may be small in situations where reception is excellent and 18+ GPS+GLONASS satellites can be tracked, but a reduction in reported error estimates can still be seen.
I have added a config flags and the necessary config sentences in my code, but only for Galileo. I have not checked in the changes to my fork on Github yet because there are still some open questions:
1. What should be the default - 2 or 3 GNSS systems?
2. Should BeiDou also be supported (as an alternative to Galileo)?
Regarding BeiDou: in my tests with different BN chips, I found that they do not all support BeiDou, even if they report the same firmware version (3.0.1). One chip ignores setting BeiDou on completely, another chip seems to accept the setting. It would be interesting to hear about other chips. I also do not have any data if adding BeiDou improves accuracy.
—
Reply to this email directly, view it on GitHub, or unsubscribe.
You are receiving this because you are subscribed to this thread.Message ID: ***@***.***>

Jim-Flex, 2022-10-11:
Hi Jan,
Is this what you mean?

Originally I had no setting in the config.txt, then I realised I didn’t so put the line "gnss”:3  It didn’t make any difference.

Cheers,
Jim

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

RP6conrad, 2022-10-11:
Default is 3 gnss, but there are beitian modules with old firmware, these will only receive 2 gnss. (Ublox rom core 3.01 versus rom core 2.01). Verzonden vanaf mijn Galaxy
-------- Oorspronkelijk bericht --------Van: Flex ***@***.***> Datum: 11/10/22  11:42  (GMT+01:00) Aan: RP6conrad/ESP-GPS-Logger ***@***.***> Cc: RP6conrad ***@***.***>, Comment ***@***.***> Onderwerp: Re: [RP6conrad/ESP-GPS-Logger] Support logging using 3 GNSS systems (Issue #4)

Hi Jan,

Is this what you mean?

Originally I had no setting in the config.txt, then I realised I didn’t so put the line "gnss”:3  It didn’t make any difference.

Cheers,

Jim

> On 11 Oct 2022, at 3:12 pm, RP6conrad ***@***.***> wrote:

>

>

> Can you give me the settings in U-center for 3 different GNSS (see prontscreen) ?

> I have several Beitian BN GPS which have still ROM version 2, these do not support Gallileo.

> I prefer to have default 2 GNSS, and configurable 3. I prefer Galileo, but I have no experience with 3 GNSS settings. Maybe with ROM version 2 only Beidou is possible.

>

>

>

>

>

> Greetings, Jan.

> Verzonden vanuit Mail voor Windows

>

> Van: prichterich

> Verzonden: zaterdag 14 mei 2022 16:08

> Aan: RP6conrad/ESP-GPS-Logger

> CC: Subscribed

> Onderwerp: [RP6conrad/ESP-GPS-Logger] Support logging using 3 GNSS systems(Issue #4)

>

> The current firmware version does not set which GNSS systems are used, so the default (GPS + GLONASS) is used. User can pre-configure GPS chips (other than the BN180) to use other systems using u-center, but that requires extra equipment (FTDI cable) and skills (using u-center).

> I propose to add config flags to use additional GPS systems, in particular Galileo. The BN220, 280, and 880 chips all can handle 3 systems at 5 Hz without problems, and probably also at 10 Hz (I usually use 5 Hz, but I think decrepit uses 10 Hz with his prototypes).

> The general thinking is tracking satellites from 3 systems gives higher accuracy than from 2 systems. The benefits may be small in situations where reception is excellent and 18+ GPS+GLONASS satellites can be tracked, but a reduction in reported error estimates can still be seen.

> I have added a config flags and the necessary config sentences in my code, but only for Galileo. I have not checked in the changes to my fork on Github yet because there are still some open questions:

> 1. What should be the default - 2 or 3 GNSS systems?

> 2. Should BeiDou also be supported (as an alternative to Galileo)?

> Regarding BeiDou: in my tests with different BN chips, I found that they do not all support BeiDou, even if they report the same firmware version (3.0.1). One chip ignores setting BeiDou on completely, another chip seems to accept the setting. It would be interesting to hear about other chips. I also do not have any data if adding BeiDou improves accuracy.

> —

> Reply to this email directly, view it on GitHub, or unsubscribe.

> You are receiving this because you are subscribed to this thread.Message ID: ***@***.***>

>

> —

> Reply to this email directly, view it on GitHub <https://github.com/RP6conrad/ESP-GPS-Logger/issues/4#issuecomment-1274191688>, or unsubscribe <https://github.com/notifications/unsubscribe-auth/AD56P25FVWGYUHYMZMG2YTTWCUHMNANCNFSM5V5TYOLQ>.

> You are receiving this because you are subscribed to this thread.

>

—Reply to this email directly, view it on GitHub, or unsubscribe.You are receiving this because you commented.Message ID: ***@***.***>

RP6conrad, 2023-01-18:
Actual SW gives different options for 3 GNSS : GPS + Glonas + Galileo, or GPS + Glonas + Beidou

Closed 2023-01-18.

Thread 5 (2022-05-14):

Support NAV-SAT sentences

prichterich, 2022-05-14:
The current firmware only logs NAV-PVT sentences. But for evaluation and debugging, it can often be useful to also have NAV_SAT sentences to see which satellites where used, and what the signal levels (C/N0) were. For example, I recently ordered two BN220 chips which behaved quite differently. One started slower, and often tracked fewer satellites. Looking at signal levels from NAV_SAT sentences showed that the chip with fewer satellites had an average signal strength that was about 3 db lower.

I propose to add a config flag that allows logging of NAV_SAT sentences. NAV-SAT sentences can be 4 x larger than NAV-PVT sentences when many satelites are tracked, so transmission rates are an issue. This can be partly addressed by logging NAV-SAT only every 10th cycle, which works fine at 5 Hz.  The default should be to not log NAV-SAT sentences, since this information is not normally used to determine speeds.

I have modified the local copy of my fork to support NAV_SAT logging, but not pushed the changes to GitHub for various reasons. If anyone else wants to also use NAV-SAT, please let me know, and I'll put the change up.

RP6conrad, 2022-05-14:
I did take a look for the NAV_SAT sentences, but as they have a variable length, It seemed not so easy for me. The baud rate is now 19200 baud, which is fine for the NAV_PVT. Is there a setting in the M8N so that the NAV_SAT is ***@***.*** Hz, and the ***@***.*** Hz ? Otherwise, a higher baud rate is necessary.
For the moment, I have no plans for logging the NAV_SAT, but as someone will evaluate three GNSS, it could be usefull/necessary.

Greetings, Jan.

Verzonden vanuit Mail voor Windows

Van: prichterich
Verzonden: zaterdag 14 mei 2022 16:18
Aan: RP6conrad/ESP-GPS-Logger
CC: Subscribed
Onderwerp: [RP6conrad/ESP-GPS-Logger] Support NAV-SAT sentences (Issue #5)

The current firmware only logs NAV-PVT sentences. But for evaluation and debugging, it can often be useful to also have NAV_SAT sentences to see which satellites where used, and what the signal levels (C/N0) were. For example, I recently ordered two BN220 chips which behaved quite differently. One started slower, and often tracked fewer satellites. Looking at signal levels from NAV_SAT sentences showed that the chip with fewer satellites had an average signal strength that was about 3 db lower.
I propose to add a config flag that allows logging of NAV_SAT sentences. NAV-SAT sentences can be 4 x larger than NAV-PVT sentences when many satelites are tracked, so transmission rates are an issue. This can be partly addressed by logging NAV-SAT only every 10th cycle, which works fine at 5 Hz. The default should be to not log NAV-SAT sentences, since this information is not normally used to determine speeds.
I have modified the local copy of my fork to support NAV_SAT logging, but not pushed the changes to GitHub for various reasons. If anyone else wants to also use NAV-SAT, please let me know, and I'll put the change up.
—
Reply to this email directly, view it on GitHub, or unsubscribe.
You are receiving this because you are subscribed to this thread.Message ID: ***@***.***>

RP6conrad, 2023-01-01:
Support for NAV_SAT sentences will be in the next update. The rate will be 1/10 of the NAV_PVT rate. It can be set in the configuration. I noticed that GPS-Results cannot handle ubx files correctly with NAV_SAT, as there appear missing points when NAV_SAT msg with the same iTow is in the ubx. Uploading to GP3S will not work with these ubx files !

RP6conrad, 2023-01-18:
NavSat is supported, can be switched on/off over the settings. Rate is 10% of the Nav Pvt

Closed 2023-01-18.

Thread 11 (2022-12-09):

Uploading bin files

Rolzzz, 2022-12-09:
Hello there,

Directions are not very clear on what files to upload...
I'm up to here
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
but then what bin file(s) I load etc it get very vague...

Even if I want to try the esp32 download tool the documentation points to google drive rather than here
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

happy to help with clarifying documentation process if needed.

Thanks!

RP6conrad, 2022-12-09:
You need to install the ES32 download tool (for a Windows system) :
https://www.espressif.com/en/support/download/other-tools

If you connect the T5 board over USB, it should be recognized as a “virtual serial port” in Windows. If not, you need to install the correct driver.
Then, you have to download the “Flash Bin files” : https://github.com/RP6conrad/ESP-GPS-Logger/tree/master/Flash_Bin_files
These flash bin files are only needed the first time the board is flashed.
Then you dowload the bin file with the latest sw, here you need to know which kind of e-paper : B73, BN or B74 : https://github.com/RP6conrad/ESP-GPS-Logger/tree/master
Choose the latest SW version in the Bin_Files_Bxx folder (now SW5.61).
You now have downloaded 4 files, these you needed in your download tool. After choosing these files, and setting the adresses, you can flash the T5 board over usb.
Thats it, normally it should work.
Let me know if you have problems !!

Greetings, Jan.

Verzonden vanuit Mail voor Windows

Van: Rolzzz
Verzonden: vrijdag 9 december 2022 6:16
Aan: RP6conrad/ESP-GPS-Logger
CC: Subscribed
Onderwerp: [RP6conrad/ESP-GPS-Logger] Uploading bin files (Issue #11)

Hello there,
Directions are not very clear on what files to upload...
I'm up to here

but then what bin file(s) I load etc it get very vague...
Even if I want to try the esp32 download tool the documentation points to google drive rather than here

happy to help with clarifying documentation process if needed.
Thanks!
—
Reply to this email directly, view it on GitHub, or unsubscribe.
You are receiving this because you are subscribed to this thread.Message ID: ***@***.***>

Rolzzz, 2022-12-09:
Hi Jan,

Thanks for the quick response!
Hopefully last silly question, how do I tell the e-paper differences?

is this what I'm looking for?

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

I tried it, but I'm not seeing anything on the screen... my finish screen is blue, not green like your documentation

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

Freezer-SD, 2022-12-09:
What hardware do you use? It looks like you have a separate screen of 2.66inch?!?
This is what I use (see attached photo). When you receive the unit, it is listed on the bottom.

Simon

Verzonden vanaf mijn Galaxy

-------- Oorspronkelijk bericht --------
Van: Rolzzz ***@***.***>
Datum: 09-12-2022 10:03 (GMT+01:00)
Aan: RP6conrad/ESP-GPS-Logger ***@***.***>
Cc: Subscribed ***@***.***>
Onderwerp: Re: [RP6conrad/ESP-GPS-Logger] Uploading bin files (Issue #11)

Hi Jan,

Thanks for the quick response!
Hopefully last silly question, how do I tell the e-paper differences?

is this what I'm looking for?

[image]<https://user-images.githubusercontent.com/29428938/206661283-4f8a260e-5a28-4735-9943-6a49953bea18.png>

I tried it, but I'm not seeing anything on the screen... my finish screen is blue, not green like your documentation

[image]<https://user-images.githubusercontent.com/29428938/206664944-ecb2f14b-ed6e-4c57-94a7-c8225304d88b.png>

—
Reply to this email directly, view it on GitHub<https://github.com/RP6conrad/ESP-GPS-Logger/issues/11#issuecomment-1344033120>, or unsubscribe<https://github.com/notifications/unsubscribe-auth/AXUAXP7RMWUB4FNZEHNOW6LWMLYWRANCNFSM6AAAAAASY5XU2I>.
You are receiving this because you are subscribed to this thread.Message ID: ***@***.***>

Rolzzz, 2022-12-09:
> What hardware do you use? It looks like you have a separate screen of 2.66inch?!? This is what I use (see attached photo). When you receive the unit, it is listed on the bottom. Simon Verzonden vanaf mijn Galaxy
> […](#)
> -------- Oorspronkelijk bericht -------- Van: Rolzzz ***@***.***> Datum: 09-12-2022 10:03 (GMT+01:00) Aan: RP6conrad/ESP-GPS-Logger ***@***.***> Cc: Subscribed ***@***.***> Onderwerp: Re: [RP6conrad/ESP-GPS-Logger] Uploading bin files (Issue #11) Hi Jan, Thanks for the quick response! Hopefully last silly question, how do I tell the e-paper differences? is this what I'm looking for? [image]<https://user-images.githubusercontent.com/29428938/206661283-4f8a260e-5a28-4735-9943-6a49953bea18.png> I tried it, but I'm not seeing anything on the screen... my finish screen is blue, not green like your documentation [image]<https://user-images.githubusercontent.com/29428938/206664944-ecb2f14b-ed6e-4c57-94a7-c8225304d88b.png> — Reply to this email directly, view it on GitHub<[#11 (comment)](https://github.com/RP6conrad/ESP-GPS-Logger/issues/11#issuecomment-1344033120)>, or unsubscribe<https://github.com/notifications/unsubscribe-auth/AXUAXP7RMWUB4FNZEHNOW6LWMLYWRANCNFSM6AAAAAASY5XU2I>. You are receiving this because you are subscribed to this thread.Message ID: ***@***.***>

Hi Simon,

I accidentally ordered this one...
https://www.aliexpress.com/item/1005002474854718.html

Tip - do not jump onto aliexpress after too many beers...

So whilst I now wait for the proper one I thought I'd get my head around process...
I had hoped it was all compatible, guess not...

Will have to shelve this one for something else once I get familiar with how the esp32 all work.

Rolzzz, 2022-12-09:
> On a new T5 screen, it is on the left bottom. If you have a totally different screen, chances are high that the screen will not work. It has to compiled with another library. Can you give me more info about the screen used ? I can see for the library. Verzonden vanuit Mail voor Windows Van: Freezer-SD Verzonden: vrijdag 9 december 2022 10:10 Aan: RP6conrad/ESP-GPS-Logger CC: RP6conrad; Comment Onderwerp: Re: [RP6conrad/ESP-GPS-Logger] Uploading bin files (Issue #11) What hardware do you use? It looks like you have a separate screen of 2.66inch?!? This is what I use (see attached photo). When you receive the unit, it is listed on the bottom. Simon Verzonden vanaf mijn Galaxy
> […](#)
> -------- Oorspronkelijk bericht -------- Van: Rolzzz ***@***.***> Datum: 09-12-2022 10:03 (GMT+01:00) Aan: RP6conrad/ESP-GPS-Logger ***@***.***> Cc: Subscribed ***@***.***> Onderwerp: Re: [RP6conrad/ESP-GPS-Logger] Uploading bin files (Issue #11) Hi Jan, Thanks for the quick response! Hopefully last silly question, how do I tell the e-paper differences? is this what I'm looking for? [image]<https://user-images.githubusercontent.com/29428938/206661283-4f8a260e-5a28-4735-9943-6a49953bea18.png> I tried it, but I'm not seeing anything on the screen... my finish screen is blue, not green like your documentation [image]<https://user-images.githubusercontent.com/29428938/206664944-ecb2f14b-ed6e-4c57-94a7-c8225304d88b.png> — Reply to this email directly, view it on GitHub<[#11 (comment)](https://github.com/RP6conrad/ESP-GPS-Logger/issues/11#issuecomment-1344033120)>, or unsubscribe<https://github.com/notifications/unsubscribe-auth/AXUAXP7RMWUB4FNZEHNOW6LWMLYWRANCNFSM6AAAAAASY5XU2I>. You are receiving this because you are subscribed to this thread.Message ID: ***@***.***> — Reply to this email directly, view it on GitHub, or unsubscribe. You are receiving this because you commented.Message ID: ***@***.***>

this is what it looked like prior to turning it on... and I realised it was the wrong one
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
Rolzzz, 2022-12-09:
I am just hoping to use this one to familiarise myself with how all things esp32 (arduino?) work... been into Linux and RaspberryPi's for a number of years and thought this would be a great way to learn these units.

I'm so used to having an ssh console with logs or even just screen dumps rolling over so I can understand whats going on...
here it seems I'm just looking at a blinking green light to give me an indication of whats going on... it's all very new to me.

Please don't waste any time on this... I'll just wait for the correct (smaller) version to arrive.

Rolzzz, 2022-12-09:
> Can you give me your email, then I send you the correct bin file. Dont think this is possible over github....
I couldn't find the bin file u were mentioning :)

rrschmid_at_gmail_dot_com

Rolzzz, 2022-12-09:
thanks for sending file @RP6conrad but still no joy...  sadly without access to a console or log file I'm really powerless to know what is going on with these units... is the process even working, am I doing it correctly at all? No idea... 😢

RP6conrad, 2022-12-09:
If the ESP32 is booted, you can try to connect to the “Acces Point” : just see to al the Wifi SSID and search for ESP32AP. Connect with password “password” en go with a browser to IP 192.168.4.1
This works for the first 120s after boot, if no config file is present.

Greetings, Jan.

Verzonden vanuit Mail voor Windows

Van: Rolzzz
Verzonden: vrijdag 9 december 2022 12:26
Aan: RP6conrad/ESP-GPS-Logger
CC: RP6conrad; Mention
Onderwerp: Re: [RP6conrad/ESP-GPS-Logger] Uploading bin files (Issue #11)

thanks for sending file @RP6conrad but still no joy... sadly without access to a console or log file I'm really powerless to know what is going on with these units... is the process even working, am I doing it correctly at all? No idea... 😢
—
Reply to this email directly, view it on GitHub, or unsubscribe.
You are receiving this because you were mentioned.Message ID: ***@***.***>

RP6conrad, 2022-12-09:
Do you have the T-U2T interface for this board ? This is necessary for connect to your PC !! This is the usb-serial converter !
I guess you have this board :
https://nl.aliexpress.com/item/1005002474854718.html

Greetings, Jan.
Verzonden vanuit Mail voor Windows

Van: Rolzzz
Verzonden: vrijdag 9 december 2022 12:26
Aan: RP6conrad/ESP-GPS-Logger
CC: RP6conrad; Mention
Onderwerp: Re: [RP6conrad/ESP-GPS-Logger] Uploading bin files (Issue #11)

thanks for sending file @RP6conrad but still no joy... sadly without access to a console or log file I'm really powerless to know what is going on with these units... is the process even working, am I doing it correctly at all? No idea... 😢
—
Reply to this email directly, view it on GitHub, or unsubscribe.
You are receiving this because you were mentioned.Message ID: ***@***.***>

Rolzzz, 2022-12-09:
> Do you have the T-U2T interface for this board ? This is necessary for connect to your PC !! This is the usb-serial converter ! I guess you have this board : https://nl.aliexpress.com/item/1005002474854718.html Greetings, Jan. Verzonden vanuit Mail voor Windows Van: Rolzzz Verzonden: vrijdag 9 december 2022 12:26 Aan: RP6conrad/ESP-GPS-Logger CC: RP6conrad; Mention Onderwerp: Re: [RP6conrad/ESP-GPS-Logger] Uploading bin files (Issue #11) thanks for sending file @RP6conrad but still no joy... sadly without access to a console or log file I'm really powerless to know what is going on with these units... is the process even working, am I doing it correctly at all? No idea... 😢 — Reply to this email directly, view it on GitHub, or unsubscribe. You are receiving this because you were mentioned.Message ID: ***@***.***>

Yes I have this board and the usb/serial converter... I can see the ESP32AP wifi AP but cannot connect to it.
Tried off my computer and iphone but no luck... is there anyway to upload the config.txt file? Do I need to use this method?
https://docs.google.com/document/d/1jIxAyi6wQ-Z860W548Xg--x6Ld8MBHJh7SCCWhSgnAs/edit?usp=sharing
I got it up and going but had no idea what files to upload

tritondm, 2022-12-09:
Hi
You can Upload the config.txt to your SD Card by copy the File on your Computer. Or if you connected to the AP you can enter the IP 192.168.4.1 in your connected device in the Browser of your choice and there your able to Change your current config.
greets

Rolzzz, 2022-12-09:
yeah tried all that but no luck... closing case and will try again when I get a supported device.

Closed 2022-12-09.

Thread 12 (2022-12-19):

Config.txt file issues

Rolzzz, 2022-12-19:
Hello there,

Few things I've noticed in the config file - this might be something to do with in built web browser

"cal_speed" always reverts back to "3.6km/h" instead of staying on pre-set, mine is "1.9438 knots"

most annoying one

ssid only keeps first word of ssid - for example my ssid is "Moonbase Alpha 2.4Ghz" but in web browser config it only shows "Moonbase" so when I change a setting and don't re-set this I lose wifi connectivity and have to try to connect via the default AP

Board and Sail logo links in web browser both point board link https://www.seabreeze.com.au/img/photos/windsurfing/19375156.jpg so choosing Severne Sail presents Simmer logo (number 8)

RP6conrad, 2022-12-20:
The cal_speed is a bug, will be fixed in the next update.
The SSID is also a bug, has Probably to do with the white spaces in the SSID name. I’ll try to fix that.
I’ ll check also the board and sail logo.
I guess that you are on firmware SW5.61 ?

Greetings, Jan.

Verzonden vanuit Mail voor Windows

Van: Rolzzz
Verzonden: maandag 19 december 2022 23:27
Aan: RP6conrad/ESP-GPS-Logger
CC: Subscribed
Onderwerp: [RP6conrad/ESP-GPS-Logger] Config.txt file issues (Issue #12)

Hello there,
Few things I've noticed in the config file - this might be something to do with in built web browser
"cal_speed" always reverts back to "3.6km/h" instead of staying on pre-set, mine is "1.9438 knots"
most annoying one
ssid only keeps first word of ssid - for example my ssid is "Moonbase Alpha 2.4Ghz" but in web browser config it only shows "Moonbase" so when I change a setting and don't re-set this I lose wifi connectivity and have to try to connect via the default AP
Board and Sail logo links in web browser both point board link https://www.seabreeze.com.au/img/photos/windsurfing/19375156.jpg so choosing Severne Sail presents Simmer logo (number 8)
—
Reply to this email directly, view it on GitHub, or unsubscribe.
You are receiving this because you are subscribed to this thread.Message ID: ***@***.***>

Rolzzz, 2022-12-20:
Hi Jan,

yes on FW SW5.61

obviously none of these are a show stopper, but thought I'd be helpful with making note of things that I come across.

Cheers!

Freezer-SD, 2022-12-20:
Would it be possible to have multiple SSID's? Like in the phone, one can store multiple ones.
Another tip I heard is about OTA updates. Once having wifi, it should be able to check the latest firmware on github and downloading it. Just single button to update it in the web interface would do the trick.

RP6conrad, 2022-12-21:
There is a new update with bugfixes and  changes.   I all files (ubx, gpx, gpy, sbp) are logged, 5Hz is the advised rate. @10Hz, lost points are possible.
 * SW5.63
* Added GPX file format (log @ 1Hz)
 * Added GPY file format (first draft, but can be read now with last version of gps-speedreader)
 * If no config file : Wifi AP waiting time = 120 s
 * Bugfix config webserver : no switching to km/h if knots was set.
 * Bugfix for SSID with white spaces
 * Added support for BN266 e-paper (still 213 layout !!)
 * Changed GPS-parser union to struct, every ubx message has its own struct now
 * Added ubx nav dop Msg for extracting HDOP
 * Added ubx mon ver Msf for extracting sw / hw version ublox
 * Changed baudrate ublox to 38400, necessary for 10Hz navDOP + navPVT
 * Correction timestamp list files with FTP
 * Added sail logo "Severne" = 10 (the same as the board logo)
 * Added board logo "F2" = 10
 * Added watchtdog for WAKE UP screen (hangs sometimes after OTA)
 * Added loadbalance for flushfiles()

Rolzzz, 2022-12-21:
Thanks Jan,

Can we just run ubx and gpy and still keep 10Hz?
Is it if we log all formats that the lost points happen?

As doing testing to get authorisation for GPST eligibility device, my priority is more accuracy with 10Hz over config.txt file issues.

RP6conrad, 2022-12-22:
With a Sandisk Ultra 16GB card, I had next results :
@5Hz, ubx, gpy, sbp and gpx logged together with no lost points
@10Hz, ubx, gpy, sbp and gps logged together gives lost points
@10Hz, ubx, gpy and sbp logged together no lost points.

Gpy format is still a draft version, and only gps-speedreader can read them now. There are still some issues with handling lost points, and local time. Peter is working on it.

For testing purposes, I advice to log ubx and sbp together @10Hz. Best to send out the ubx files for comparison, as these have the highest resolution and the most information in it.
But check always your own files with gps-speedreader (the “Message window” reports lost points) !

In daily “surf live”, I use 5Hz : file size, and less critical for the “acceleration” limit which is used in all sites (GP3S, GPSTMC…)
The most important thing for a good quality signal is however the positioning of the logger : on the head or on your upperarm gives the best reception quality, and thus the lowest sAcc / hDOP values.

Greetings, Jan.

Verzonden vanuit Mail voor Windows

Van: Rolzzz
Verzonden: donderdag 22 december 2022 0:26
Aan: RP6conrad/ESP-GPS-Logger
CC: RP6conrad; Comment
Onderwerp: Re: [RP6conrad/ESP-GPS-Logger] Config.txt file issues (Issue #12)

Thanks Jan,
Can we just run ubx and gpy and still keep 10Hz?
Is it if we log all formats that the lost points happen?
As doing testing to get authorisation for GPST eligibility device, my priority is more accuracy with 10Hz over config.txt file issues.
—
Reply to this email directly, view it on GitHub, or unsubscribe.
You are receiving this because you commented.Message ID: ***@***.***>

Rolzzz, 2022-12-22:
Jan ur a Wizard!
All 3 items were were sorted!

Happily resolve this one!
I really now can't wait to test on the water once my water proof paint arrives.

Merry Christmas to you! 🎄🎅🏻

Closed 2022-12-22.

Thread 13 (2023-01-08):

Web page improvements

prichterich, 2023-01-08:
The web page for downloading and editing files is great. I suggest several improvements:

1. Sort files by date in descending order, so that the newest files are on top. Users typically are most interested in the newest file.
2. Support folders: show folders in the view, and allow opening folders to see their contents. I typically keep all files for a GPS on the SD card, but move older files to a separate folder. Currently, the web page shows the contents of all subdirectories, so moving files to a different folder does not gain anything.
3. Hide "hidden" files added by various operating systems. On macOS, that's trash and spotlight folders, and sometimes "copies" of files that start with a dot (not really copies, but rather OS specific info about the files). Windows adds a couple of directories with volume information.

Of the changes above, the first one is relevant to all users. The third one is not important to users with sealed units, since they never put the SD cards into a computer. The second change is somewhere in between, since files can be moved to new folders with ftp clients.

RP6conrad, 2023-01-08:
As the order of the file listing is coming from the FAT32 system, it is not quite easy to change this order. Probably  you have to store all the reported filenames in RAM, then order them again, and then make the a new listing. I found a intresting article about this subject : https://www.codeproject.com/articles/95721/fat-32-sorter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

Rolzzz, 2023-01-08:
I've been playing with ChatGPT and posted this question into it... can it be of any help?

ME:
I have an esp32 with a webserver and wish to present saved files sorted by newest date, how can I do this?

ChatGPT:
You can use the stat function to get the modification time of a file, and then sort the list of files based on this value. Here is some example code in C that demonstrates this:

#include <stdio.h>
#include <stdlib.h>
#include <sys/stat.h>
#include <time.h>

// Comparison function for qsort
int compare_modification_time(const void* a, const void* b) {
  struct stat file_a, file_b;
  if (stat((const char*)a, &file_a) == -1 || stat((const char*)b, &file_b) == -1) {
    perror("Error getting file modification time");
    exit(EXIT_FAILURE);
  }
  return difftime(file_b.st_mtime, file_a.st_mtime);
}

int main(int argc, char* argv[]) {
  if (argc < 2) {
    printf("Usage: %s <file1> <file2> ...\n", argv[0]);
    exit(EXIT_FAILURE);
  }

  // Sort the files by modification time
  qsort(argv + 1, argc - 1, sizeof(char*), compare_modification_time);

  // Print the sorted list of files
  for (int i = 1; i < argc; i++) {
    printf("%s\n", argv[i]);
  }

  return 0;
}

This code sorts the command line arguments (which are assumed to be filenames) based on their modification time, and then prints the sorted list of filenames. You can modify this code to suit your needs, such as reading the filenames from a directory instead of the command line arguments.

RP6conrad, 2023-01-14:
There is a other (simpler) way : It should be possible to sort the "table" on the client side : after loading al the filenames, a script should sort again the files with descending dates. But javascript is not my cup of tea.....

tritondm, 2023-01-14:
I did IT but struggling with some JavaScript Bugs i Work in IT.. greets

RP6conrad ***@***.***> schrieb am Sa., 14. Jän. 2023, 19:20:

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

Freezer-SD, 2023-01-17:
I found a nice and easy to understand explanation of sorting tables in java at https://www.w3schools.com/howto/howto_js_sort_table.asp
There are 2 sections and I like the 2ns solution where you click on the header to sort it by:
Sort Table by Clicking the Headers
Click the headers to sort the table.
Click "Name" to sort by names, and "Country" to sort by country.
The first time you click, the sorting direction is ascending (A to Z).
Click again, and the sorting direction will be descending (Z to A):
One can try/customize the script as well at
https://www.w3schools.com/howto/tryit.asp?filename=tryhow_js_sort_table_desc

There are also examples available to do filtering:
https://www.w3schools.com/howto/howto_js_filter_table.asp
This one provides a search field where text can be typed. If you wanted a GPY file one could simply type a GPY in the search.
But it will be better to restrict it to a certain available file extensions (ubx, gpy, gpx, sbp) through a dropdown filtering:
https://www.w3schools.com/howto/howto_js_filter_dropdown.asp

More fancy without clicking would be a hover able dropdown preventing additional clicking:
https://www.w3schools.com/howto/howto_css_dropdown.asp

In practice there is so much space on the sdcard that I don’t think it is required to delete anything. As long as the access to the files is great.
I’m not sure if it is possible, but during storing the file to keep index files that are stored with the summary results (max2s, max10s, 5x10s, mile, distance). In that way you could also show or sort the files with the additional info. Currently we use large file names to keep all info in the name. Not sure if we can either store it in the metadata or in a separate file (owner, gps-receiver, firmware version, date, time, location, etc.)

For the configuration file html page, the info column consumes a lot of space.
Once users know what it means it does not make sense to show. It could be shown as alternative tekst on a info.gif i

I like to compact the views as much as possible and with minimum amount of clicks.
I’m not sure if you can detect the device (mobile, tablet or PC format), but the styles should be optimized for best user experience.

I hope this helps.

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

RP6conrad, 2023-01-17:
Actually, that was the base where I started ! I made a simple javascript function, which just order the table with the latest date first in the table. But after sorting, the buttons did not work anymore…
I took me some time, but with some changes, it works now fine.
Before sorting, you have to wait until the page is completely loaded. As there is a event when the page is loaded, I used that for starting the sorting.
The reason for limiting the number of files, is the time that is needed for loading. As you never know when which file will be loaded (is a FAT32 issue), you just have to wait until all files are loaded.
I use FTP to delete files (WinSCP), goes fast en reliable.
I will upload the new SW tomorrow (still some testing to do) :
* SW 5.71
 * Again bugfix for time in gpy file (offset year 1970->1900, month->-1)
 * Removed #include timelib.h
 * Removed listing of directorys in webserver
 * Add sortTable() after DOM is loaded : now the files are ordered by date after loading all filenames !
 * Timestamp files with FTP command MLSD is now UTC
 * Add type of ublox to .txt file + e-paper shut down
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
Freezer-SD, 2023-01-20:
Hi,

I just loaded the v5.71 M10 B74 and had a look at the menus.

I notice that the files are properly sorted by reverse date (good). But, it does not add the control to the user.
Clicking inside the header sorting it the way the user wants as was shown on https://www.w3schools.com/howto/tryit.asp?filename=tryhow_js_sort_table_desc both ordered and reverse by another click.

I notice there is a “/” in front of the name. Once downloaded the “/”has become a “_” in front of the filename. I don’t think it is intentional.

Would it be possible to configure the timestamp format? It contains a lot of characters. Usually month and day would be OK, but sometimes you might want to see the year and hours perhaps. “MMM dd HH” would do it for me, to make it more compact. But it might be set in the config.txt.

The size has 4 significant numbers in kB or Mb. For me it would be good to always be Mb. Since there are 4 digits, the small .txt files will show as 0.002Mb very clear that it is small.

Instead having 4 separate rows, the file types could be combined in a single row.
Name
Size
Timestamp
Download
Delete
/2008311709_Simon_M10S.ubx
7.904 MB
2023-01-04 17:54:28
Download
Delete
/2008311709_Simon_M10S.gpy
1.596 MB
2023-01-04 17:54:28
Download
Delete
/2008311709_Simon_M10S.gpx
2.919 MB
2023-01-04 17:54:28
Download
Delete
/2008311709_Simon_M10S.txt
2.803 KB
2023-01-04 17:54:28
Download
Delete

Into more compact (no redundant info). I understand this requires quite a bit of additional table formatting:
Name<Sort:%20by%20File%20name%20;%20again%20for%20reverse%20order>
Info
Date<Sort:%20by%20Date%20;%20again%20for%20reverse%20order>
Types
2008311709_Simon_M10S
i<Open:%20Info%20session%20txt%20file%20file>
0.003 MB
delete<delete:%20all%20session%20files>
Jan-04 17:54
UBX<download:%20UBX-file>
7.904 MB
delete<delete:%20UBX%20file>
GPY<download:%20GPY%20file>
1.596 MB
delete<delete:%20GPY%20file>
GPX<download:%20GPX%20file>
2.919 MB
delete<delete:%20GPX%20file>

Instead of having to click for the info, perhaps it could be a user defined value listed in the info.
For me the 5x10sec, so one immediately can judge the session
Name<Sort:%20by%20File%20name%20;%20again%20for%20reverse%20order>
Date<Sort:%20by%20Date%20;%20again%20for%20reverse%20order>
avg 5_best_runs
Types
2008311709_Simon_M10S
delete<delete:%20all%20session%20files>
Jan-04 17:54
64.094 km/h
UBX<download:%20UBX-file>
7.904 MB
delete<delete:%20UBX%20file>
GPY<download:%20GPY%20file>
1.596 MB
delete<delete:%20GPY%20file>
GPX<download:%20GPX%20file>
2.919 MB
delete<delete:%20GPX%20file>

The header of the page could contain the “Sleep_info” from the config file (in my case “Simon M10”), rather than:
***@***.***

Perhaps included with the GPS-ESP logo, board and sail logos as selected in the config file plus the preferred GPS website (to be added to the config.txt):
[Logo  Description automatically generated]<https://github.com/RP6conrad/ESP-GPS-Logger>  Simon M10   <http://192.168.68.122/>  [Icon  Description automatically generated] <https://windsurf.star-board.com/>    [A picture containing text, sign  Description automatically generated] <https://ga-windsurfing.com/> ***@***.*** <https://www.gps-speedsurfing.com/mygps.aspx>

Trying to make things nice.

Kind regards, Simon

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

RP6conrad, 2023-01-20:
@Freezer :
 I have to check or this can be / ignored.
Timestamp format in the filename can easily be configured, but it has to stay "unique". Otherwise, It could be overwritten by accident.
If you want to see the AVG from a session, the txt file must be read and these values must be parsed. Can be done, but not so simple.

@prichterich
To limit the number of files that is listed, we could easily make a "Archive" dir. All files older then xx days would be renamed and transferred to this "Archive". They will not be in the file listing anymore, but they will still be on the SD-card. When the ESP is on Wifi, it can get NTP time, and check for old files. Nr of days can be in the config.txt

KingJimmy27, 2025-04-30:
I have read all the articles and browsed through the Seabreeze posts but I
do not see the details of how to build the logger in Arduino.
I assume the base file is Rtos5.ino
<https://github.com/RP6conrad/ESP-GPS-Logger/blob/master/Rtos5.ino> and I
have put all the other files and folders on RP6conrad/ESP-GPS-Logger: GPS
logger for Speedsurfing, based on ESP32 & Ublox M8N hardware.
<https://github.com/RP6conrad/ESP-GPS-Logger>
into E:\James\Documents\Arduino\libraries\ESP-GPS-Logger.
I have set  the Arduino / library versions : as suggested on the Github
page.
I am not sure if this is correct because I get errors thrown up by the
Arduino.
I am using Arduino 2.3.6 in the VisualMicro environment.
Any suggestions would be great.

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

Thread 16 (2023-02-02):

Support firmware updates in AP mode

prichterich, 2023-02-02:
Currently, firmware updates fail if the logger is in AP mode, and the computer used does not have a second connection to the internet (e.g. over Ethernet). The apparent cause is that the firmware update web page uses code that is downloaded from the internet (jquery, googleapis, or similar). A computer with just one internet connection that is connected to the logger in AP mode cannot access these resources.

It should be possible to include the needed resources in the firmware, and change the webpage to point to the included resources.

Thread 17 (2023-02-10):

Distance screen improvements

prichterich, 2023-02-10:
I'm thinking about perhaps doing distance so I checked the distance screen for the first time. Several improvements are desirable:
1. Always show distance in km (not meters). A precision of 0.1 is sufficient. In the test drive I did, the distance was shown in meters. After 10 km, the last digit overlaps with the "R" (for run distance).
2. Replace run distance with battery percentage. Run distance rarely, if ever, makes sense when going for distance. But battery charge can be an issue when doing 10+ hour sessions. Seeing that battery gets low can be a reminder to take a break and charge the battery. Even a half hour charge at 0.5 A for 30 minutes can add a couple of hours of battery life. This is an issue for units with smaller batteries, but can also become an issue with large batteries when they get older. Here on Lake George, someone posts a 200+ km session almost every day.
3. Consider a better layout, for example 2 lines with the same height, one for current speed and one for distance. Battery charge could be shown as an icon, like in older firmware versions, on the side. When doing distance, seeing total distance is just as important as current speed, and glasses or sunglasses may be quite dirty after a few hours on the water, making it hard to read smaller numbers.

Freezer-SD, 2023-02-10:
Having a configurable active- and stat-screen with row/column definitions including sizes (discrete steps S/M/L) and a way to identify what text/graph/logo would go where would help everyone. It probably would need a separate screen config to be controlled from a HTML page that will show how the screen would look like.

The number of fonts and sizes are limited. Not sure how much space they are taking.

There is not yet a check, if the number of digits increases, it will be printed on the next line. It would be better to reduce the digits to prevent it from happening. Same is true for logos/icons, they have a fixed size, but a check to make it fit, once it is configurable, is needed.

Maximizing font size, reducing empty/white space will help most of us.

We could start to check the existing screen permutations and define what flexibility would be required to define these.

For some they will swap speed with distance, or alphas or nautical miles, whatever it is that you're trying to improve and will stimulate to push a bit more, longer...

Verzonden vanaf mijn Galaxy

-------- Oorspronkelijk bericht --------
Van: prichterich ***@***.***>
Datum: 10-02-2023 06:55 (GMT+01:00)
Aan: RP6conrad/ESP-GPS-Logger ***@***.***>
Cc: Subscribed ***@***.***>
Onderwerp: [RP6conrad/ESP-GPS-Logger] Distance screen improvements (Issue #17)

I'm thinking about perhaps doing distance so I checked the distance screen for the first time. Several improvements are desirable:

  1.  Always show distance in km (not meters). A precision of 0.1 is sufficient. In the test drive I did, the distance was shown in meters. After 10 km, the last digit overlaps with the "R" (for run distance).
  2.  Replace run distance with battery percentage. Run distance rarely, if ever, makes sense when going for distance. But battery charge can be an issue when doing 10+ hour sessions. Seeing that battery gets low can be a reminder to take a break and charge the battery. Even a half hour charge at 0.5 A for 30 minutes can add a couple of hours of battery life. This is an issue for units with smaller batteries, but can also become an issue with large batteries when they get older. Here on Lake George, someone posts a 200+ km session almost every day.
  3.  Consider a better layout, for example 2 lines with the same height, one for current speed and one for distance. Battery charge could be shown as an icon, like in older firmware versions, on the side. When doing distance, seeing total distance is just as important as current speed, and glasses or sunglasses may be quite dirty after a few hours on the water, making it hard to read smaller numbers.

—
Reply to this email directly, view it on GitHub<https://github.com/RP6conrad/ESP-GPS-Logger/issues/17>, or unsubscribe<https://github.com/notifications/unsubscribe-auth/AXUAXPZOIBHLVNHFPUOCIIDWWXJ4ZANCNFSM6AAAAAAUXM3E2Y>.
You are receiving this because you are subscribed to this thread.Message ID: ***@***.***>

prichterich, 2023-02-18:
I noticed a bug in E_paper.cpp:
            `if(Ublox.total_distance/1000,0<9999)
`
Seems the line should read
            `if(Ublox.total_distance/1000.0<9999)
`
C always uses periods for the decimal point, not commas. Good example for mistakes that permissive languages like C or Perl allow that would be caught by the compiler in languages like Java, where using a comma here would be a syntax error.

prichterich, 2023-02-18:
I modified the distance code to show total distance and time. Here is what my code now looks like:
 ```
       if(field==5){
            display.setFont(&FreeSansBold12pt7b);
            display.print("D ");
            display.setFont(&FreeSansBold18pt7b);
            if(Ublox.total_distance/1000.0 < 999)
            display.print(Ublox.total_distance/1000,0);//Total distance in meter, als test run_distance
            else
            display.print(Ublox.total_distance/1000000,1);//Total distance in km, als test run_distance
            display.setCursor(offset+130,24);
            display.setFont(&FreeSansBold12pt7b);
            display.print(" ");
            display.setFont(&FreeSansBold18pt7b);
            display.print(time_now);
            }
         if(field==6){

```
There's enough space to show 4 digits before the comma.

prichterich, 2023-02-18:
The one thing that I'd like to see that's still missing for distance is a battery level indicator.

RP6conrad, 2023-02-18:
This will be in the next update. I noticed that there was a bug in this comparison, but I did not know why. The bat indicator will be on the right.`
` if(field==5){
            if(config.speed_large_font==1){
              bar_position=40;//test voor bigger font
              display.setCursor(offset,36);
              display.setFont(&FreeSansBold12pt7b);
              display.print("Dist ");
              display.setFont(&SansSerif_bold_46_nr);
              display.print(Ublox.total_distance/1000000,1);//Total distance in km, als test run_distance
              if(Ublox.total_distance/1000000>99.9){
                display.setFont(&FreeSansBold12pt7b);
                display.print(" km");
                }
            }
            else{
              display.setCursor(offset,36);
              display.setFont(&FreeSansBold12pt7b);
              display.print("Dist ");
              display.setFont(&FreeSansBold18pt7b);
              display.print(Ublox.total_distance/1000000,1);//Total distance in km, als test run_distance
              display.setFont(&FreeSansBold12pt7b);
              display.print(" km");
             }
     
            Bat_level(offset+222,0);
`

RP6conrad, 2023-02-23:
Distance + bat level is now in SW 5.73

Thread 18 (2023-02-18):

Auto-detect baud rate and chip type

prichterich, 2023-02-18:
At initialization, the firmware should determine the baud rate to use, and the type of chip (M8 or M10 based). Currently, supporting different chips is done by setting flags in the code, which is adequate for initial development, but not distribution.

Baud rate can be determined by sending "get info" commands, and checking that an "ACK" response as well as the expected content is received, trying different baud rates.

Basically, this means that the software verifies at the start that communication with the GPS works as expected. This should be done, anyway, but becomes essential when supporting different GPS chips and chip generations.

RP6conrad, 2023-02-23:
Is now in the latest  SW 5.73. Auto detect start with 9600bd, message MON VER to ublox. HW-version is evaluated, if not readable, switch to 38400 bd and evaluate MON VER again. Tested with Beitian BN (M8 9600bd), Beitian BE (M10 38400bd), Mateksys (M10 9600bd) and Bainianxing (M10 38400 bd).

Closed 2023-02-23.

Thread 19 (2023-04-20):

From zero to hundred km/h time

tampoldandre, 2023-04-20:
Hello! **10 Hz** is nice feature of the logger, thanks!

Is it possible to calculate time in device to measure 0 to 100 km/h?
Processing file, it is easy to find it, but would be nice to see on screen right after "run" also.
100+ km/h is often exceeded in winter https://www.gps-icesailing.com/ ..

Andre

RP6conrad, 2023-04-20:
100 km/h can be logged already with the esp-gps as it is. The only issue is the e-paper screen layout, for font size for the speeds is only capable for display 99.9 km/h (3 digits).
In my car, I tested this several times, and the only issue is the layout of the screen.
So, the logger is certainly suited for icesailing !
To calculate acceleration from 0 km/h  to 100 km/h this can be done. But the accuracy would be less then 0.1s, as there are some delays involved, in the gps itself, and some in the logger.
This feature is for motor / car test ?

Greetings, Jan.

Verzonden vanuit Mail voor Windows

Van: tampoldandre
Verzonden: donderdag 20 april 2023 10:08
Aan: RP6conrad/ESP-GPS-Logger
CC: Subscribed
Onderwerp: [RP6conrad/ESP-GPS-Logger] From zero to hundred km/h time (Issue #19)

Hello! 10 Hz is nice feature of the logger, thanks!
Is it possible to calculate time in device to measure 0 to 100 km/h?
Processing file, it is easy to find it, but would be nice to see on screen right after "run" also.
100+ km/h is often exceeded in winter https://www.gps-icesailing.com/ ..
Andre
—
Reply to this email directly, view it on GitHub, or unsubscribe.
You are receiving this because you are subscribed to this thread.Message ID: ***@***.***>

tampoldandre, 2023-04-20:
Yes, max speed, max2, 10sec and avg over 100 km/h seems to work very well and will be measured next winter again on ice sailing.

The only thing I would like to see is calculated acceleration from 0 km/h  to 100 km/h. In summer yes, with motobike/car... I manually checked SBP file ESP GPS recorded and I can see that time from measured point speed less < 1 m/s (or 1 km/h) and then point where speed first time goes > 100km/h is ~4.2 seconds I would like to see on screen :) ... (0.1s/0.2s accuracy is very OK)

I mean: Screen choices if speed < 1 m/s (Statistics of session) and Screen choices if speed is > 1m/s to choose this calculated field...

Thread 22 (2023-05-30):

Autobauding and chip detection not reliable

prichterich, 2023-05-30:
I have experienced random failures with the automatic detection of baud rate and chip at startup with FW 5.74 and 5.75. This affected 2 different units with Beitian BN220 chips which never had problems with versions up to 5.72.

This is not well reproducible. I have seen issues first after switching the BN220 against a Beitian BE220, and the going back to the original chip. The display still showed 38kBaud after the switch, although the recording seemed to work ok. At other times, the startup screens reported not being able to identify the chip. While at home, the communication still worked fine (judging by the unit showing that it got satellites), but when I used it in a windsurf session today, it staid at "waiting for satellites" (v. 5.74), and did not record at all. Back at home, it discovered M8 @ 9600 correctly several times in a row.

The vast majority of GPS units will be built with one kind of GPS chip, and then keep this chip from then on. In any sealed units, this cannot change after the built. So rather than doing an autodetect every time, it may make more sense to autodetect only on an "as needed" basis (e.g. when verifying the chip type using previously saved information fails).

RP6conrad, 2023-05-31:
I could make a field in the configuration with "Auto detect GPS on", @startup then autodetect, then writing the type of gps in the same field. So, this field can then have  next values :

1. Autodetect on
2. M8@9600bd
3. M8@38400bd
4. M10@9600bd
5. M10@38400bd
So, the user can always "force" the type of gps.

prichterich, 2023-05-31:
That looks like a very good solution. The software purist in me would also suggest to clean up the autobauding code, and to support detecting other baud rates and the M9. But there are no good reasons to choose an M9 that hold up to closer inspection, and no U-blox/Beitian GPS units that come with other baud rates, so all that can wait a long time (or forever).

RP6conrad, 2023-05-31:
I have just ordered a ublox M9 (m9140 chip), as Beitian has now the BK-line for a very reasonable price ! Lets see if we can log @ 25 Hz !Verzonden vanaf mijn Galaxy
-------- Oorspronkelijk bericht --------Van: prichterich ***@***.***> Datum: 31/05/23  14:59  (GMT+01:00) Aan: RP6conrad/ESP-GPS-Logger ***@***.***> Cc: RP6conrad ***@***.***>, Comment ***@***.***> Onderwerp: Re: [RP6conrad/ESP-GPS-Logger] Autobauding and chip detection not reliable (Issue #22)
That looks like a very good solution. The software purist in me would also suggest to clean up the autobauding code, and to support detecting other baud rates and the M9. But there are no good reasons to choose an M9 that hold up to closer inspection, and no U-blox/Beitian GPS units that come with other baud rates, so all that can wait a long time (or forever).

—Reply to this email directly, view it on GitHub, or unsubscribe.You are receiving this because you commented.Message ID: ***@***.***>

prichterich, 2023-05-31:
I got an original u-blox M9 chip a year or so ago, and was quite disappointed to find out that the chip automatically reduced the number of satellites used to 16 when logging at 10 Hz and higher. For the M8, the Beitian chips actually were better than original u-blox M8s with respect to rates and multiple GNSS systems. If you're lucky, you may see the  same for the M9. I would not bet on it, though - I think the u-blox M10 can do 4 GNSS systems simultaneously, but the BE220 and 250 chips are limited to 3.
Re 25 Hz, even at 10 Hz, the observed "noise" while windsurfing is dominated by movements of the arm/hand/boom that the GPS is mounted to, and not by random noise. That's quite obvious if you look at nauti or 1 h for units attached at different positions. Alpha differences with 2 boom mounted units is somewhat similar - the results often differ at a level that is significant because the slight difference int turn diameter for inner and outer unit.
Once you go beyond 5 Hz, the reported "accuracy" estimates calculated by Gaussian error propagation become more and more meaningless, at least for windsurfing and similar applications. I think that even replacing 10 Hz raw measurement with 1 or 2 Hz averages would be very close in _actual_ accuracy for 2 second speeds, and even more so for 10 seconds and beyond. The biggest difference is in "top speed" - but that is always overstated by single-point measurements, and this error only gets **worse** is you use higher rates.

RP6conrad, 2023-06-15:
With the SW 5.76, the function "Autodetect ublox" is done with a new device, then the result is saved to the EEPROM memory. Next boot, no Autodetect anymore. If needed, the Autodetect can be activated again over the configuration menu.
Added support for the M9 ublox.

Closed 2023-06-15.

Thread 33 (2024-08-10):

Date and time wrong in GPY files

prichterich, 2024-08-10:
In version 5.85, the date and time is wrong in .gpy files. With a time zone of GMT-4, the error is -40 hours. The error was not present in version 5.82 (which I suggest to remove from the BIN downloads since both buttons and AP functions do not work properly).

The attached zip archive contains pairs of small .ubx and .gpy files created with different software versions on 8/10/24, between 10 and 11:40 am EDT. Only the .gpy files created with version 5.85 show the wrong date (8/8 instead of 8/10) and the wrong time (16 hours too early). The .ubx files all have the correct date and time. The gpy.h files on GitHub does not show any recent changes that would explain the difference (last change: last year is shown).

[GPY_error.zip](https://github.com/user-attachments/files/16570129/GPY_error.zip)

RP6conrad, 2024-08-10:
There is indeed a big  error in some timezones. This has been introduced with the DST correction. In the gpy.h file is also a error, as I use mktime() function for UTC timestamp. This function returns localtime, but I need UTC time...
Will be corrected in the next update....

Thanks for reporting this error  !

Greetings, Jan
________________________________
Van: prichterich ***@***.***>
Verzonden: zaterdag 10 augustus 2024 17:57
Aan: RP6conrad/ESP-GPS-Logger ***@***.***>
CC: Subscribed ***@***.***>
Onderwerp: [RP6conrad/ESP-GPS-Logger] Date and time wrong in GPY files (Issue #33)

In version 5.85, the date and time is wrong in .gpy files. With a time zone of GMT-4, the error is -40 hours. The error was not present in version 5.82 (which I suggest to remove from the BIN downloads since both buttons and AP functions do not work properly).

The attached zip archive contains pairs of small .ubx and .gpy files created with different software versions on 8/10/24, between 10 and 11:40 am EDT. Only the .gpy files created with version 5.85 show the wrong date (8/8 instead of 8/10) and the wrong time (16 hours too early). The .ubx files all have the correct date and time. The gpy.h files on GitHub does not show any recent changes that would explain the difference (last change: last year is shown).

GPY_error.zip<https://github.com/user-attachments/files/16570129/GPY_error.zip>

—
Reply to this email directly, view it on GitHub<https://github.com/RP6conrad/ESP-GPS-Logger/issues/33>, or unsubscribe<https://github.com/notifications/unsubscribe-auth/AOBIYSZFP3KW735CU4WJSZLZQYZ6BAVCNFSM6AAAAABMJ55TG6VHI2DSMVQWIX3LMV43ASLTON2WKOZSGQ2TSMJUGUYTMOA>.
You are receiving this because you are subscribed to this thread.Message ID: ***@***.***>

RP6conrad, 2024-08-12:
Corrected version SW 5.87 is on github. Error was in the TZ (timezone) string, 4 h offset was seen as 40h, and in the gpy file, the local time (40h difference with UTC) was stored in the frames...

Greetings, Jan.
________________________________
Van: prichterich ***@***.***>
Verzonden: zaterdag 10 augustus 2024 17:57
Aan: RP6conrad/ESP-GPS-Logger ***@***.***>
CC: Subscribed ***@***.***>
Onderwerp: [RP6conrad/ESP-GPS-Logger] Date and time wrong in GPY files (Issue #33)

In version 5.85, the date and time is wrong in .gpy files. With a time zone of GMT-4, the error is -40 hours. The error was not present in version 5.82 (which I suggest to remove from the BIN downloads since both buttons and AP functions do not work properly).

The attached zip archive contains pairs of small .ubx and .gpy files created with different software versions on 8/10/24, between 10 and 11:40 am EDT. Only the .gpy files created with version 5.85 show the wrong date (8/8 instead of 8/10) and the wrong time (16 hours too early). The .ubx files all have the correct date and time. The gpy.h files on GitHub does not show any recent changes that would explain the difference (last change: last year is shown).

GPY_error.zip<https://github.com/user-attachments/files/16570129/GPY_error.zip>

—
Reply to this email directly, view it on GitHub<https://github.com/RP6conrad/ESP-GPS-Logger/issues/33>, or unsubscribe<https://github.com/notifications/unsubscribe-auth/AOBIYSZFP3KW735CU4WJSZLZQYZ6BAVCNFSM6AAAAABMJ55TG6VHI2DSMVQWIX3LMV43ASLTON2WKOZSGQ2TSMJUGUYTMOA>.
You are receiving this because you are subscribed to this thread.Message ID: ***@***.***>

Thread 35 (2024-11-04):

Battery calibration gives wrong values for plug-in charging

prichterich, 2024-11-04:
I use all my ESP-GPS loggers in Gopro housings, and charge them via cable. The auto calibration feature does not work well for this setup at all. With a fully charged battery (I always use USB meters), the battery level is indicated as 74%, not 100%. The reason is that the voltage delivered by the charging cable is higher than the battery voltage, but this higher voltage is used for calibration. So when a unit wakes up while being charged, it bases the calibration on the cable voltage, not the battery voltage. I get very low values near 1.6 from the autocalibration, while the actual values tend to be around 1.75.

This is a problem that does not seem to have a workaround because any manual edits of the calibration number are completely ignored. It seems the logic is that the calibration value can only be adjusted downwards, not upwards. For plug-in charging, this is wrong.

prichterich, 2024-11-04:
It seems that the problem with the wrong calibration value is very consistent.Re-installing the current firmware (5.89) did not fix the problem, not even after first installing version 5.71. In 5.71, I can see that the value I manually edited in the config file is used, but when then installing 5.89 again, the previous value of 1.61 is used again.
Connection the charging cable increases the displayed batter percentage by about 10% to 12% within less than a minute; unplugging the charging cable leads to a drop in the same range and time frame.

RP6conrad, 2024-11-05:
The calibration is now stored in the EEPROM mem, and this is not deleted with standard flashing with Arduino. Maybe it is better to have a possibility to "override" the calibration, and do it manual. It is on the list...

prichterich, 2024-11-05:
Have you checked if the battery voltage reading is accurate while charging wireless? My (rather limited) understanding is that wireless chargers also provide 5 V, just like cables, which would mean the same issue could occur with wireless charging, too.

RP6conrad, 2024-11-06:
The charging of the lipo is done with a charging chip, so the USB or Wireless charger voltage has no direct influence on the charging voltage. The measuring of the Bat voltage is directly on the battery, so this should never exceed 4.2 Volt, even as the supply voltage is 5 Volt.
But there is indeed the issue that the voltage drops is charging stops.....

[cid:d30b0307-cce2-4d61-9d71-058e4ce9004e]
________________________________
Van: prichterich ***@***.***>
Verzonden: dinsdag 5 november 2024 14:54
Aan: RP6conrad/ESP-GPS-Logger ***@***.***>
CC: RP6conrad ***@***.***>; State change ***@***.***>
Onderwerp: Re: [RP6conrad/ESP-GPS-Logger] Battery calibration gives wrong values for plug-in charging (Issue #35)

Have you checked if the battery voltage reading is accurate while charging wireless? My (rather limited) understanding is that wireless chargers also provide 5 V, just like cables, which would mean the same issue could occur with wireless charging, too.

—
Reply to this email directly, view it on GitHub<https://github.com/RP6conrad/ESP-GPS-Logger/issues/35#issuecomment-2457243235>, or unsubscribe<https://github.com/notifications/unsubscribe-auth/AOBIYS65XJAOVUTGMQQVGTDZ7DE2LAVCNFSM6AAAAABRFGBR3CVHI2DSMVQWIX3LMV43OSLTON2WKQ3PNVWWK3TUHMZDINJXGI2DGMRTGU>.
You are receiving this because you modified the open/close state.Message ID: ***@***.***>

prichterich, 2024-11-07:
You're assumptions are incorrect. The charging voltage has to be higher than the current battery voltage for any charging to occur. While charging, you measure the charging voltage, even if you measure directly at the battery.

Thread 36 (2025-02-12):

API password (for webinterface?

IHateNameStealers, 2025-02-12:
I must be doing something wrong here or missed something while following the how-to.

After successfully flashing the LilyGO TTGO T-Display  (in my case) with T_display5.91.bin, I would like to set up some things through the web server.

Activating the web server (holding the top button for several seconds) works fine, and I do see the message "AP active." However, after connecting to the ESP32AP over Wi-Fi, it asks for a password! (It could be that the password is shown on the LilyGO TTGO T display, but not all lines fit on the screen, and after several seconds the screen blanks.)

The only password I've set is when installing the OTAWebUpdater, but I've never set an AP password!

So, can anyone here help me with this?

Thank you.

IHateNameStealers, 2025-02-12:
Never mind

As usual I always find the needed info after posting a question (yes I did search already for some time)

I found the default password in: https://github.com/RP6conrad/ESP-GPS-Logger/blob/master/Rtos5.ino

So it is: **password**

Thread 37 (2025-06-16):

README.md user manual link not working (Google Docs)

eriwst, 2025-06-16:
First of all, thank you for your work on this great project. Unfortunately, the link to the user manual in the README.md does not work.

At least the link currently points to a page with the message: The file you requested has been deleted.

RP6conrad, 2025-06-17:
My mistake, cleaned Google Drive a bit too much. Trying to recover the files now...Greetings, Jan.Verzonden vanaf mijn Galaxy
-------- Oorspronkelijk bericht --------Van: eriwst ***@***.***> Datum: 16/06/2025  21:55  (GMT+01:00) Aan: RP6conrad/ESP-GPS-Logger ***@***.***> Cc: Subscribed ***@***.***> Onderwerp: [RP6conrad/ESP-GPS-Logger] README.md user manual link not working (Google Docs) (Issue #37) eriwst created an issue (RP6conrad/ESP-GPS-Logger#37)
First of all, thank you for your work on this great project. Unfortunately, the link to the user manual in the README.md does not work.
At least the link currently points to a page with the message: The file you requested has been deleted.

—Reply to this email directly, view it on GitHub, or unsubscribe.You are receiving this because you are subscribed to this thread.Message ID: ***@***.***>

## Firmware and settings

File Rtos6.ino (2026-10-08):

#include <SD_MMC.h>
#include <sd_defines.h>
#include <sd_diskio.h>
#include <WiFi.h>
#include <WiFiAP.h>
#include <WiFiClient.h>
#include <WiFiGeneric.h>
#include <WiFiServer.h>
#include <WiFiSTA.h>
#include <WiFiType.h>
#include "FS.h"
#include "SPI.h"
#include "sys/time.h"
#include "soc/timer_group_struct.h"
#include "soc/timer_group_reg.h"
#include "Arduino.h"
#include "Ublox.h"
//#include "E_paper_266.h"//changing the E_paper : delete the build directory (can be found in the compile output)
#include "E_paper.h"
#include "SD_card.h"
#include "GPS_data.h"
#include "ESP32FtpServerJH.h"
#include "OTA_server.h" 
#include <esp_task_wdt.h>
#include "freertos/task.h"//added V3
#include <driver/rtc_io.h>
#include <driver/gpio.h>
#include <lwip/apps/sntp.h>
#include <esp32-hal.h>
#include <time.h>
//#include <EEPROM.h>
#include "Definitions.h"
#include <LittleFS.h>
#include "rom/rtc.h"
#include "track_speed.h"
#include "ESP_functions.h"
#include <Preferences.h>

const char* ssid = config.ssid; //WiFi SSID
const char* password = config.password; //WiFi Password
const char* ssid2 = config.ssid2; //WiFi SSID
const char* password2 = config.password2; //WiFi Password
const char* soft_ap_ssid = "ESP32AP"; //accespoint ssid
const char* soft_ap_password = "password"; //accespoint password
#define MAX_API_KEY_LENGTH 60
//char apiKey[MAX_API_KEY_LENGTH] = ""; // Globale char-array voor je HTTPS-key
Preferences preferences;
bool ap_mode=false;
bool sleep_mode=false;
//bool isUploading=false;
extern bool reset_boot; 
// Globale variabelen voor het traject en de metingen
Line_2D startLijn;
Line_2D finishLijn;
GPS_point poort1;
GPS_point poort2;
LijnMetingState startState;
LijnMetingState finishState;
Doppler_track result_track_speed;
// Variabelen om de status van de run bij te houden
uint32_t exacteGpsTijdStart = 0;  // Gewogen iTOW start (ms)
uint32_t exacteGpsTijdFinish = 0; // Gewogen iTOW finish (ms)
bool runIsBezig = false;
// Afstand tussen de poorten (wordt eenmalig berekend in setup)
double trajectAfstandMeters = 0.0;
double gemiddeldeSnelheid_mmps;
double doppler_track_speed;
double projected_doppler_track_speed;
double track_speed[10];
double doppler_speed[10];
double projected_doppler_speed[10];
uint8_t track_hour[10];
uint8_t track_minute[10];
double track_time;
LijnPassageResultaat startRes;
LijnPassageResultaat finishRes;

// Globale variabelen en handles voor de RTOS upload-taak
//volatile bool isUploading = false;         // Geeft aan of er een actieve upload bezig is
//bool apiKeyValid = true;                   // Wordt false bij een 401 of 403 fout
//TaskHandle_t UploadTaskHandle = NULL;      // De handle waarmee we de taak kunnen beheren of deleten
//SemaphoreHandle_t fileSystemMutex = NULL;  // Voorkomt dat de GPS-logger en de upload-taak tegelijk de SD-kaart gebruiken
// Prototypes (Forward declarations) zodat setup() weet dat ze bestaan
//void uploadTask(void * pvParameters);
//void probeerUpload(const char* filepath);
//void gemarkeerdAlsVerzonden(const char* filepath);

void setup() {
  Serial.begin(115200);
  Serial.print("Actual CPU freq @ boot"); Serial.println (getCpuFrequencyMhz());
  #ifdef T5_V2_4_GPIO12   //T5 board version 2.4 needs gpio12 high voor the e-paper
   pinMode(12, OUTPUT);
   digitalWrite(12, HIGH);
  #endif
  pinMode(2, INPUT_PULLUP);//for SD_MMC mode....
  /*
  EEPROM.begin(EEPROM_SIZE);
  config.ublox_type = EEPROM.readByte(0);Serial.print("EEPROM ublox_type=");Serial.println(config.ublox_type);
  config.M10_high_nav=EEPROM.readByte(1);
 // Serial.println("Force setting to autodetect!");
//  EEPROM.writeByte(0,255);EEPROM.commit();
//  config.ublox_type=255;
  if(config.M10_high_nav>3){config.M10_high_nav=0;EEPROM.writeByte(1,NO_M10_GPS);EEPROM.commit();} 
  Serial.print("EEPROM M10_high_nav=");Serial.println(config.M10_high_nav);
  */
    // Start Preferences in read-only modus (false)
  preferences.begin("gps_config", false);
  // Lees de waarden uit. Als een waarde nog niet bestaat in de NVS (bijv. eerste start),
  // wordt automatisch de standaardwaarde (het 2e argument) geladen.
  config.ublox_type = preferences.getUChar("ublox_type", AUTO_DETECT); 
  Serial.print(F("Preferences ublox_type=")); 
  Serial.println(config.ublox_type);

  config.M10_high_nav = preferences.getUChar("M10_high_nav", NO_M10_GPS);
  if (config.M10_high_nav > 3) {
    config.M10_high_nav = 0;
    // Sla direct de gecorrigeerde waarde op
    preferences.putUChar("M10_high_nav", NO_M10_GPS);
  } 
  Serial.print(F("Preferences M10_high_nav=")); 
  Serial.println(config.M10_high_nav);
  // --- LEES DE API KEY UIT ---
  // We halen de string op. Als deze nog niet bestaat, laden we "sk_live_leeg"
  String geladenKey = preferences.getString("api_key", "sk_live_leeg");
  geladenKey.toCharArray(apiKey, MAX_API_KEY_LENGTH); 
  Serial.print(F("Preferences API Key Short = "));
  Serial.println(apiKeyShort);
  // Zet de globale char-array of string om naar een tijdelijke String om te bewerken
  String apiKeyStr = String(apiKey);
  //apiKeyShort = String("");
  if (apiKeyStr.length() > 20) {
    // Knip de eerste 20 karakters af (index 0 tot 20) en voeg puntjes toe
    apiKeyShort = apiKeyStr.substring(0, 20) + "...";
  } else {
    // Als de key korter is dan 20 karakters, toon hem dan volledig
    apiKeyShort = apiKeyStr;
  }
  // Sluit de preferences-namespace netjes af
  preferences.end();

  //print_reset_reason(rtc_get_reset_reason(0));//Find out the reset reason, if no SW-reset-> back to deep sleep !
  if(reset_boot==true) {setCpuFrequencyMhz(80);}
  print_wakeup_reason(); //Print the wakeup reason for ESP32, go back to sleep is timer is wake-up source !
  Serial.println("setup Serial");
  Serial.println("Serial Txd is on pin: "+String(TX));
  Serial.println("Serial Rxd is on pin: "+String(RX));
  /*
  RTC_highest_read=EEPROM.readInt(2);
  if((RTC_highest_read<STARTVALUE_HIGHEST_READ)|(RTC_highest_read>MAXVALUE_HIGHEST_READ)){
    EEPROM.writeInt(2,STARTVALUE_HIGHEST_READ) ;
    EEPROM.commit();
    RTC_highest_read=STARTVALUE_HIGHEST_READ;
    Serial.println("Eeprom highest read set to starting value !!");
    }
  */  
  RTC_calibration_bat= FULLY_CHARGED_LIPO_VOLTAGE/RTC_highest_read;
  Serial.print("RTC_calibration_bat EEPROM = ");
  Serial.println(RTC_calibration_bat);
  Serial.println("Configuring WDT...");
  esp_task_wdt_init(WDT_TIMEOUT,true);
  esp_task_wdt_add(NULL); //add current thread to WDT watch
  analog_mean = analogRead(PIN_BAT);//fill FIR filter
  SPI.begin(SPI_CLK, SPI_MISO, SPI_MOSI, ELINK_SS); //SPI is used for SD-card and for E_paper display !
  //sdSPI.begin(SDCARD_CLK, SDCARD_MISO, SDCARD_MOSI, SDCARD_SS);//default 20 MHz gezet worden !
  struct timeval tv = { .tv_sec =  0, .tv_usec = 0 };
  settimeofday(&tv, NULL);

  if (!SD_MMC.begin("/sdcard", true)) {  
        sdOK = false;
        Serial.println("No SDCard found!");
        if (!LITTLEFS.begin(FORMAT_LITTLEFS_IF_FAILED)) {
          Serial.println("LITTLEFS Mount Failed");
          return;
        } 
    else {
      Serial.print("LITTLEFS Mounted with success. Total space= ");
      int total_bytes = LITTLEFS.totalBytes();
      int used_bytes = LITTLEFS.usedBytes();
      Serial.print(total_bytes);
      Serial.println(" bytes");
      Serial.print("Free space left= ");
      Serial.print(total_bytes-used_bytes);
      Serial.println(" bytes");
      LITTLEFS_OK = true;
      //Boot_screen();
      loadConfiguration(filename, filename_backup, config);  // load config file
      Serial.print(F("Print config file..."));
      if (sdOK|LITTLEFS_OK) printFile(filename); 
    }
  } 
  else {
        sdOK = true;Serial.println("SDCard found!");
        //int *real_freq=0;
        //sdmmc_host_get_real_freq(SDMMC_HOST_SLOT_1,*real_freq);
        uint64_t cardSize = SD_MMC.cardSize() / (1024 * 1024);
        uint64_t totalBytes=SD_MMC.totalBytes() / (1024 * 1024);
        uint64_t usedBytes=SD_MMC.usedBytes() / (1024 * 1024);
        freeSpace=totalBytes-usedBytes;
       // Serial.printf("SD Card Speed: %d MHz\n", real_freq/1000); 
        Serial.printf("SD Card Size: %lluMB\n", cardSize); 
        Serial.printf("SD Total bytes: %lluMB\n", totalBytes); 
        Serial.printf("SD Used bytes: %lluMB\n", usedBytes); 
        Serial.printf("SD free space: %lluMB\n", totalBytes-usedBytes); 
        testFileIO(SD_MMC, "/test.txt");
        Serial.println(F("Loading configuration..."));// Should load default config 
        loadConfiguration(filename, filename_backup, config); // load config file
        Serial.print(F("Print config file...")); 
        printFile(filename); 
  } 
  RTC_calibration_bat= config.cal_bat;
  Serial.print("RTC_calibration_bat = ");
  Serial.println(RTC_calibration_bat);
  //Short_push12.begin(12,1); //gpio12 now as output for screen V2.4
  Short_push19.begin(19,0);
  Short_push39.begin(39,1);
  // 1. Voer hier je Google Maps coördinaten in van jouw windsurf speed-strip
  poort1 = { config.p1_lat, config.p1_lon }; 
  poort2 = { config.p2_lat, config.p2_lon };
  // 2. Bereken de vaste afstand
  trajectAfstandMeters = berekenAfstandVincenty(poort1, poort2);
  // 3. Genereer automatisch de haakse start- en finishlijn op basis van de vaaras
  TrajectLijnen mijnTraject = genereerLoodrechteLijnen(poort1, poort2);
  startLijn  = mijnTraject.startLijn;
  finishLijn = mijnTraject.finishLijn;
  RTC_screen_orientation = config.screen_orientation;
  Boot_screen();

   if(RTC_voltage_bat<RTC_minimum_voltage_bat){
      RTC_OFF_screen=1;//Simon screen with info text !!!
      char tekst[32] = "";
      sprintf(tekst, "Shutdown low bat  @ %.1f V\n",RTC_minimum_voltage_bat);
      logERR(tekst);
      strcpy(RTC_Sleep_txt,"Shut down Low Bat !");
      Shut_down();
   }
  if(reset_boot==true){
      RTC_OFF_screen=1;//Simon screen with info text !!!
      char tekst[32] = "";
      sprintf(tekst, "Sleep after reset");
      logERR(tekst);
      strcpy(RTC_Sleep_txt,"Shutdown after reset!");
      Shut_down();
  }
  setCpuFrequencyMhz(240);
  Update_screen(BOOT_SCREEN);
  Serial.print("Actual CPU freq before Wifi.begin(): "); Serial.println (getCpuFrequencyMhz());
  WiFi.onEvent(OnWiFiEvent);
  WiFi.mode(WIFI_STA);
  WiFi.begin(ssid, password);
  Serial.print("T5 MAC adress: ");
  WiFi.macAddress(mac);
  actual_ssid=ssid;
 
  Serial.println("search SSID1");
  Search_for_wifi(); 
   if ((WiFi.status() != WL_CONNECTED)&(ap_mode==false)) {
    WiFi.disconnect();
    WiFi.begin(ssid2, password2);
    actual_ssid=ssid2;  
    wifi_search=10;
   }
  if(ap_mode==false) {
    Serial.println("search SSID2");
    Search_for_wifi();
    }

  if(ap_mode==true){
    WiFi.disconnect();
    WiFi.mode(WIFI_AP);
    WiFi.softAP(soft_ap_ssid,soft_ap_password);
    wifi_search=120;
    Serial.println("search AP");
    Search_for_wifi();
  }
  
  if((WiFi.status()== WL_CONNECTED)|SoftAP_connection){
      actual_ssid=WiFi.SSID();
      Serial.println("");
      Serial.print("Connected to ");
      Serial.println(actual_ssid);
      Serial.print("IP address: ");
      Serial.println(IP_adress);
      Wifi_on=true;
      ftpSrv.begin("esp32","esp32");    //username, password for ftp
      OTA_setup();  //start webserver for over the air update
      }
  else{
      detachInterrupt(GO_TO_SLEEP_GPIO);
      Serial.println("No Wifi connection !");
      WiFi.disconnect(true);
      WiFi.mode(WIFI_OFF);
      Wifi_on=false;
      SoftAP_connection=false;
      Update_screen(GPS_INIT_SCREEN); 
      GPS_OK = setupGPS();
      Update_screen(GPS_INIT_SCREEN);
      }
  delay(100); 
  //Create RTOS task, so logging and e-paper update are separated (update e-paper is blocking, 800 ms !!)
  //xTaskCreate(
  xTaskCreatePinnedToCore(  
                    taskOne,          /* Task function. */
                    "TaskOne",        /* String with name of task. */
                    10000,            /* Stack size in bytes. */
                    NULL,             /* Parameter passed as input of the task */
                    1,                /* Priority of the task. */
                    &t1,  //&t1,
                    1);            /* Task handle. */
 
 // xTaskCreate(
  xTaskCreatePinnedToCore( 
                    taskTwo,          /* Task function. */
                    "TaskTwo",        /* String with name of task. */
                    10000,            /* Stack size in bytes was 10000, but stack overflow on task 2 ?????? now 20000. */
                    NULL,             /* Parameter passed as input of the task */
                    1,                /* Priority of the task. */
                    &t2,//&t2,
                    0);            /* Task handle. */

  // 1. Maak de Mutex aan voor de beveiliging van de SD-kaart
  fileSystemMutex = xSemaphoreCreateMutex();
#ifdef AUTO_UPLOAD_SPEEDSURF
  // 2. Start de upload-taak op KERN 0
  if (fileSystemMutex != NULL) {
    xTaskCreatePinnedToCore(
      uploadTask,             // De functie die hieronder is gedefinieerd
      "UploadTask",           // Naam van de taak (voor debugging)
      8192,                   // Stack size in bytes (ruim genoeg voor WiFiClientSecure)
      NULL,                   // Parameter die je eventueel meegeeft (niet nodig)
      1,                      // Prioriteit van de taak (laag, GPS heeft voorrang)
      &UploadTaskHandle,      // De globale handle
      0                       // <--- Kern 0 (Kern 1 draait je GPS-logger en Webserver)
    ); 
    Serial.println("Upload-manager succesvol gestart op Kern 0.");
  }
#endif  
}

void loop() { 
  /*
  int wdt_task0_duration=millis()-wdt_task0;
  int wdt_task1_duration=millis()-wdt_task1;
  int task_timeout=(WDT_TIMEOUT -1)*1000;//1 second less then reboot timeout 
  if((wdt_task0_duration<task_timeout)&(wdt_task1_duration<task_timeout)){
    feedTheDog_Task0();
    feedTheDog_Task1();
    }
  if((wdt_task0_duration>task_timeout)&(downloading_file)&(max_count_wdt_task0<MAX_COUNT_WDT_TASK0)) {
    max_count_wdt_task0++;
    feedTheDog_Task0();
    wdt_task0=millis();
    Serial.println("Extend watchdog_timeout due long download"); 
    }     
  if((wdt_task0_duration>task_timeout)&(!downloading_file)) Serial.println("Watchdog task0 triggered");
  if(wdt_task1_duration>task_timeout) Serial.println("Watchdog task1 triggered");
  */
  vTaskDelay(1);         //dit moet normaal volstaan voor watchdog
  esp_task_wdt_reset();  //en dit... Al de rest opkuisen
  Update_bat();
  delay(100); 
}

void taskOne( void * parameter )
{
 while(true){ 
   vTaskDelay(1);         //dit moet normaal volstaan voor watchdog
   esp_task_wdt_reset();  //en dit... Al de rest opkuisen
   //wdt_task0=millis();
   #if defined (GPIO12_ACTIF)
   if (Short_push12.Button_pushed())GPIO12_screen++;//toggle screen
   if (GPIO12_screen>config.gpio12_count)GPIO12_screen=0;
   if (Long_push12.Button_pushed()){ s10.Reset_stats(); s2.Reset_stats();a500.Reset_stats();} //resetten stats   
   #endif
    if(Long_push39.Button_pushed()|Long_push19.Button_pushed()) {
      sleep_mode=true;
      Serial.println("task one delete");vTaskDelete(NULL);
      }//to prevent gps boot in task one....
    static int actual_speed_field=0;  
    if (Short_push39.Button_pushed()|Short_push19.Button_pushed()){  
      if(config.Stat_screens_time==0)stat_count++;
      else actual_speed_field++;
      }
    if (actual_speed_field>config.speed_count) actual_speed_field=0;
    if (stat_count>config.screen_count)stat_count=0;
    config.field_actual=config.speed_screen[actual_speed_field];
    Field_choice=((Short_push39.long_pulse|Short_push19.long_pulse)&(config.Stat_screens_time!=0));//10s wachttijd voor menu field keuze....
   if((WiFi.status() != WL_CONNECTED)&(Wifi_on==true)&(SoftAP_connection==false)){
        Serial.println("No Wifi connection !");
        server.close();
        WiFi.disconnect(true);
        WiFi.mode(WIFI_OFF);
        Wifi_on=false; 
        sntp_stop();//no messing around with time synchronization anymore, EPOCH time is set to 0 !!! 
        printLocalTime();
        NTP_time_set=false;
        if(!GPS_OK) {
          GPS_OK = setupGPS();
        }
       }
   if((WiFi.status() == WL_CONNECTED)|SoftAP_connection){
        ftpSrv.handleFTP();        //make sure in loop you call handleFTP()!! 
        server.handleClient();
        ftpStatus=ftpSrv.cmdStatus;//for e-paper
        // Init and get the time if WLAN, create "Archive" dir if not present
        if(WiFi.status() == WL_CONNECTED){
          if(NTP_time_set==0){
            configTime(0,0,"pool.ntp.org");
            setenv("TZ",TimeZone,1);
            tzset();
            printLocalTime();
            NTP_time_set=true;
            }
          if(!SD_MMC.exists("/Archive")&sdOK){
              SD_MMC.mkdir("/Archive");
              }
          }
          #if defined USE_AUTO_OTA_UPDATE
          if ((millis() - OTA_CHECK_INTERVAL) > _lastOTACheck) {
            _lastOTACheck = millis();
            checkFirmwareUpdates();
          }
          #endif
        #if defined (STATIC_DEBUG)
        msgType = processGPS(); //debug purposes
        static int testtime;
        if((millis()-testtime)>1000){
              testtime=millis();
              Set_GPS_Time(config.timezone);
              config.timezone++;
              }
        #endif
        }
   else {msgType = processGPS(); //only decoding if no Wifi connection
          //while (Serial2.available()) { Serial.print(char(Serial2.read()));}
          if((millis()-last_gps_msg)>TIME_OUT_NAV_PVT){trouble_screen=true;}//check for time out nav-pvt msg
          else {trouble_screen=false;}
          }  
 if ( msgType == MT_NAV_DOP ) {      //Logging after NAV_DOP, ublox sends first NAV_PVT, and then NAV_DOP. 
        if((ubxMessage.navPvt.numSV>=MIN_numSV_FIRST_FIX)&((ubxMessage.navPvt.sAcc/1000.0f)<MAX_Sacc_FIRST_FIX)&(ubxMessage.navPvt.valid>=7)&(GPS_Signal_OK==false)){
              GPS_Signal_OK=true;
              first_fix_GPS=millis()/1000;
              }
        if(GPS_Signal_OK==true){
              GPS_delay++;
              }
        if ((Time_Set_OK==false)&(GPS_Signal_OK==true)&(GPS_delay>(TIME_DELAY_FIRST_FIX*config.sample_rate))){//vertraging Time_Set_OK is nu 10 s!!
         static int avg_speed;
          avg_speed=(avg_speed+ubxMessage.navPvt.gSpeed*19)/20; //FIR filter gem. snelheid laatste 20 metingen in mm/s
          if(avg_speed>(config.start_logging_speed*1000)){
            if(Set_GPS_Time(config.timezone)){            
                Time_Set_OK=true;
                Shut_down_Save_session=true;
                start_logging_millis=millis();
                Open_files();//only start logging if GPS signal is OK
                }
          }      //    Alleen speed>0 indien snelheid groter is dan 1m/s + sACC<1 + sat<5 + speed>35 m/s !!!
        }
        if ((sdOK|LITTLEFS_OK)&(Time_Set_OK==true)&(nav_pvt_message>10)&(nav_pvt_message!=old_message)){
                  old_message=nav_pvt_message;
                  //last_gps_msg=millis();
                  gps_speed=ubxMessage.navPvt.gSpeed; //hier alles naar mm/s !!
                  static int last_flush_time=0;
                  if((millis()-last_flush_time)>60000){
                      Flush_files();
                      last_flush_time=millis();
                      }
                  if((ubxMessage.navPvt.numSV<=MIN_numSV_GPS_SPEED_OK)|((ubxMessage.navPvt.sAcc/1000.0f)>MAX_Sacc_GPS_SPEED_OK)|(ubxMessage.navPvt.gSpeed/1000.0f>MAX_GPS_SPEED_OK)){
                      gps_speed=0;
                      } 
                  Log_to_SD();//hier wordt ook geprint naar serial !!
                  Ublox.push_data(ubxMessage.navPvt.lat/10000000.0f,ubxMessage.navPvt.lon/10000000.0f,gps_speed);   
                  // Vertaal binaire data naar leesbare double eenheden
                  double latNu = (double)ubxMessage.navPvt.lat / 10000000.0;
                  double lonNu = (double)ubxMessage.navPvt.lon / 10000000.0;
                  uint32_t iTOW_nu = ubxMessage.navPvt.iTOW;
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

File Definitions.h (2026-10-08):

#ifndef RTOS5_H
#define RTOS5_H

//#define STATIC_DEBUG        //indien gps test zonder snelheid en met wifi actief
//#define DLS                  //set date on march 26 1:55, to test daylightsaving
#define T5_E_PAPER           //for compiling without display funtions....
//#define GPIO12_ACTIF        //if GPIO12 is used as wake up, standard GPIO12 function is not activated !!
#define T5_V2_4_GPIO12      //GPIO12 set high @ boot for activating the screen from the Version 2.4 is necessary. Low deepsleep current 30 µA
//#define EPD_PWR_EN              (12)    // Only V2.4 Version , v2.3.1 version not have this pin
  // Power on the EPD
  //  pinMode(EPD_PWR_EN, OUTPUT);
  //  digitalWrite(EPD_PWR_EN, HIGH);

//#define USE_AUTO_OTA_UPDATE
#define VERSION 0
#define TIME_DELAY_FIRST_FIX 10 //10 navpvt messages alvorens start loggen
#define TIME_DELAY_NEW_RUN 10 //int time_delay_new_run
#define EPOCH_2022 1640995200 //start of the year 2022 1640995200
#define UBLOX_TYPE_UNKNOWN 0
#define M8_9600BD 1
#define M10_9600BD 2
#define M8_38400BD 3
#define M10_38400BD 4
#define M9_9600BD 5
#define M9_38400BD 6
#define M8_115200BD 7
#define M9_115200BD 8
#define M10_115200BD 9

#define NO_M10_GPS  0
#define M10_DEFAULT_NAV  1
#define SET_M10_HIGH_NAV 2
#define M10_HIGH_NAV_RATE 3
#define AUTO_DETECT 0xFF
#define TRACK_SPEED

/*Pin definitions**************************************************************************/
#define SPI_MOSI 23
#define SPI_MISO -1//standaard is MISO GPIO 19 !!!!
#define SPI_CLK 18
#define SDCARD_SS 13
#define SDCARD_CLK 14
#define SDCARD_MOSI 15
#define SDCARD_MISO 2
#define GO_TO_SLEEP_GPIO 39          //default 39
#define WAKE_UP_GPIO_NUM GPIO_NUM_39   //default GPIO_NUM_39 type is no int
#define GO_TO_SLEEP_PULLDOWN 19  //same function as 39, but here default is pulldown
#define HOLD_PIN 21   //pin for high side switch, is high until shutdown ready
#define RXD2 32 //yellow is Tx Ublox, Beitian white is Tx
#define TXD2 33 //green is Rx Ublox, Beitian green is Rx
#define PIN_BAT 35 //adc for bat voltage
#define UBLOX_POWER1 25
#define UBLOX_RTC_GPIO1 GPIO_NUM_25
#define UBLOX_POWER2 26
#define UBLOX_RTC_GPIO2 GPIO_NUM_26
#define UBLOX_POWER3 27
#define UBLOX_GPIO3 GPIO_NUM_27
/*Other definitions...**********************************************************************/
#define CALIBRATION_BAT_V 1.7 //voor proto 1
#define VOLTAGE_100 4.15     //reading 100% bat, after end charging voltage drops to 4.15 V
#define VOLTAGE_0 3.4       //reading 0% bat
#define VOLTAGE_LOW 25      //reading 25% bat
#define MINIMUM_VOLTAGE 0   // if lower then minimum_voltage, back to sleep.....was 3.2
#define MINIMUM_VOLTAGE_CHANGE  0.1  //refresh screen if change > 0.01
#define STARTVALUE_HIGHEST_READ 2300  //12 bit ADC, 4.2 V over voltagedivider
#define MAXVALUE_HIGHEST_READ 2700
#define TOLERANCE 100   //mean adc highest read + TOLERANCE before auto calibrate !!!
#define FULLY_CHARGED_LIPO_VOLTAGE 4200.0 // to calculate calibration factor :  4200.0/ADC value bij highest reading while charging
#define uS_TO_S_FACTOR 1000000UL /* Conversion factor for micro seconds to seconds */
#define TIME_TO_SLEEP  3600UL   //1800UL        /* Time ESP32 will go to sleep (no for 60min, only refresh screen if delta bat > 0.1 V) */
#define WDT_TIMEOUT 120             //120 seconds WDT, opgelet zoeken naar ssid time-out<dan 10s !!!
//#define MAX_COUNT_WDT_TASK0 10   // 600 seconds max downloadtime for files !!!
#define MIN_numSV_FIRST_FIX 5     //alvorens start loggen, changed from 4 to 5 7.1/2023
#define MAX_Sacc_FIRST_FIX 2     //alvorens start loggen
#define MIN_numSV_GPS_SPEED_OK 4  //min aantal satellieten voor berekenen snelheid, anders 
#define MAX_Sacc_GPS_SPEED_OK 1   //max waarde Sacc voor berekenen snelheid, anders 0
#define MAX_GPS_SPEED_OK 40       //max snelheid in m/s voor berekenen snelheid, anders 0
#define EEPROM_SIZE 32            //use 8 bytes in eeprom for saving type of ublox
#define TIME_OUT_NAV_PVT 10000    //10s time out ubx nav-pvt msg before screen "TROUBLE" 
#define FORMAT_LITTLEFS_IF_FAILED true
#define MAX_API_KEY_LENGTH 50
//#define AUTO_UPLOAD_SPEEDSURF
#endif

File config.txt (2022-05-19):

{
  "cal_bat": 1.75,
  "cal_speed":3.6,
  "sample_rate":5,
  "gnss":2,
  "speed_field":8,
  "bar_length":1852,
  "Stat_screens":321,
  "GPIO12_screens":421,
  "Logo_choice":42,
  "sleep_off_screen":11,
  "logOAO":1,
  "logUBX":1,
  "dynamic_model":0,
  "timezone":2,
  "UBXfile":"ESP_GPS",
  "Sleep_info":"Call +32 001 002 003",
  "ssid": "Your_SSID",
  "password": "Your_password"
}

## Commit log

2021-10-09 * Changes sw 5.0
    * Automatic switching to portable with overspeed (>20 m/s)
    * Extra dynamic model Automotive : 2-> automotive
    * for higher accuracy, change of datatypes to double
    * All speeds are now in mm/s (format double)
    * Added STATS3 screen with M100/M500, config.stat_field 6
    * Added Rtos5.h for general #define
    * Bugfix in new_run_detection, speed m/s -> mm/s
    * Start logging if speed>MIN_SPEED_START_LOGGING, now 2m/s
    * Added log files in oao format
    * Removed logging to csv files
    [E_paper.h, GPS_data.cpp, GPS_data.h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]
2021-11-17 * Changes sw 5.2
    * Change to proportional font 12pt and 18pt, speed screen now has 2 variables on top
    * Replace sat nr in speed screen with other variable
    * Add a alfa indicator, the actual distance from the start point is shown, has to be < 50m
    * At the same time shows the bar the alfa distance, 250 m = full bar
    * If config.field=1, automatic switching to alfa screen after jibe until 300 m
    * then Run /. AVG screen.
    * if run distance>1852 m, switch to NM view
    [E_paper.h, GPS_data.cpp, GPS_data.h]
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2022-04-25 ESP_GPS logger SW 5.49
    * changes sw 5.48
    * Added Simon screens
    * RTC offset for sleep screen
    * RTC txt for sleep screen
    * sleep_screen "speed in km/h" or "knots" depends on calibration
    * nr of stat screens are changed (e_paper.h)
    * low_bat voltage 3.1 -> go to sleep !!!
    * update STAT4 with actual run, added extra display_speed[]
    * choice GPIO12 screens with config
    * choice Logos with config
    * choice sleep-screen, off-screen with config
    * json doc 512 -> 1024 byte
    * boot screen added config fail / ok
    * SW 5.49
    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
    [config.txt]
2022-05-06 SW 5.50 fonts
    Added missing fonts + bitmapsurfbuddies.h to Fonts dir. These were not included in the adafruit GFX as they were not standard.
    [E_paper.h]
2022-05-08 Bugfix config.txt
    Bugfix in the config.txt, nr of screens to choose now extended to max 9 screens.
    [config.txt]
2022-05-19 SW 5.51
    * SW 5.51
    * new run detection, min speed of 5 m/s
    * max nr of stat screens change to 9
    * bugfix Log_to_SD() before set speed to 0 with bad reception, checksum ubx was not correct with speed 0 !!!
    * Added config.gnss : set for 3 gnss possible, works only with ublox ROM 3.0 !
    * Check for GNSS setting : ubx msg MON_GNSS
    * Add setting GNSS in txt file @ end of session
    [config.txt]
2022-05-21 SW5.52
    Bugfix Bar Graph speed runs
    [E_paper.h, GPS_data.cpp]
2022-05-29 SW5.53
    * SW 5.52
    * bugfix for bar graph
    * SW 5.53
    * bugfix for filenaming if logUBX=0 !!!
    [SD_card.cpp]
2022-06-24 SW 5.53 : Bugfixes
    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
    [E_paper.h]
2022-11-06 SW5.54
    * SW 5.54
    * Added extra Board / Sail logo's, design by Hans Scholten
    * Added variable to config.txt : "stat_speed":2, // speed less then 2 m/s -> stat screens
    * Filenr depends now from existing .txt files !! Bug if only log OAO files was active should be ok now...
    * Shutdown screen : add type of E-paper (in case you forgot...)
    * Webserver can now download and delete files from the SD-card !!!
    * Contribution from Triton_dm on github !!
    [E_paper.h, OTA_server.h, SD_card.cpp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]
2022-11-15 SW5.55
    * SW5.55
    * Bugfix for choice screens with GPIO39 after boot
    [E_paper.h]
2022-11-17 * SW5.56 * Added an upload section to the webserver * Enabled the webserver on AP Usage, prevent from stopping during downloading files * Add IP Address of the AP to display * Add a special LOGO sect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
    [E_paper.h, OTA_server.h, SD_card.cpp]
2022-11-18 SW5.56, webserver changes
    * SW5.56 (Contribution from Triton_dm on github !!)
    * Added an upload section to the webserver
    * Enabled the webserver on AP Usage, prevent from stopping during downloading files
    * Add IP Address of the AP to display
    * Add a special LOGO section > 99 and add a special logo of a beer supplier hier @Achensee/Tirol
    * Change the Webinterface to a responsive design
    * prevent delete on one click
    [E_paper.h]
2022-11-20 add the config section - first test, fix the phps downlaod from chrome on android
    [E_paper.h, GPS_data.cpp, OTA_server.h]
2022-11-22 finalize config section, do a copy after rewrite, load from filename_backup does not work yet
    [OTA_server.h, SD_card.cpp, SD_card.h]
2022-11-23 SW_changes Tritondm
    ix the download issue with phps extionsion on android chrome
    add a config section for changing config - thats the base for the next step - config credentials for gps-speedsurfing.com and upload
    after before upload a config_backup will created
    greets Andi
    [OTA_server.h]
2022-11-23 SW_5.58 (tritondm)
    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
    [OTA_server.h, SD_card.cpp]
2022-11-30 SW5.59
    * SW5.59 Bugfixes + added sbp file format
    * Changed next file for compiling with Arduino IDE 2.02 (SD(esp32) to SD)
    * C:\Users\andre\AppData\Local\Arduino15\packages\esp32\hardware\esp32\1.0.6\libraries\SD\library.properties
    * Bugfix decoding config logo, GPIO12 and stat_screen
    * Range bar_length now from 100 - 10000
    * Added new fileformat .sbp
    [ESP32FtpServerJH.cpp, E_paper.h, OTA_server.h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]
2022-12-01 SW5.60
    * SW5.60 Bugfixes + added sbp file format
    * Removed fileformat .oao
    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
    [SD_card.cpp, SD_card.h]
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2022-12-21 SW5.63_
    * Added support for BN266 e-paper
    * Correction timestamp list files with FTP
    * Added sail logo "Severne" = 10
    * Added board logo "F2" = 10
    * Bugfix for SSID with white space
    * Added watchtdog for WAKE UP screen (hangs sometimes after OTA)
    * Added loadbalance for flushfiles()
    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
    [ESP32FtpServerJH.cpp, E_paper.h, GPS_data.cpp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]
2022-12-27 SW 5.64
    * SW5.64
    * Bugfix garbage frame in gpy / ubx
    * Reboot ESP : ublox_off for 1s !!
    * Added support for ublox M10 (Mateksys maxM10s), define in Rtos.h
    * Time stat screen toggle configurable
    * bdrate back to 19200BD, should be ok for 10*100 (nav_pvt) + 10*26 bytes(nav_dop)
    * Added support for GNSS GPS + GALILEO + BEIDOU for M8 + M10
    * Correction time on sleep-screen with timezone
    [OTA_server.h, SD_card.cpp, SD_card.h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]
2022-12-28 SW5.65
    * Bugfix stat screen time
    [E_paper.h]
2022-12-29 SW5.65 38400bd bugfix...
    I was too fast, hope this works (not tested...)
    [E_paper.h, Ublox.cpp]
2023-01-02 SW5.66
    * SW 5.66
    * Added SW-version + e-paper type to Wifi-on screen + sleep screen Simon
    * baud rate back to 38400 for nav sat msg
    * Added (configurable) ubx nav sat message to ubx file, Rate = 1/10 of NAV PVT, timeshift 18.05 s for ascending order ubx msg
    * This is if you want to evaluate the signal quality of your gps (ucenter)
    * Filename with Timestamp in it, configurable
    * .sbp file corrections, problem with uploading to gp3s, header change (0xa0, 0xa2)
    * .sbp file correction for sAcc, hDOP
    * added alfa screen to 0.5h / 1h, bar_length gives time passed 30min /60 min
    * sleep_screen Simon : 500m -> 1h best
    [E_paper.h, OTA_server.h, SD_card.cpp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]
2023-01-03 SW5.67
    * NAV SAT not with polling, but over cfg msg @ 10% rate of NAV PVT
    * NAV SAT for M10 added @ 10% rate of NAV PVT
    * removed timeshift iTow NAV SAT
    * Added extra option filenaming
    * Some changes to header SBP
    * correction time bug in sleep screen
    * reset 30 min / 60 min bar if speed drops<2m/s for 120s (screen best 0.5h / 1h)
    [SD_card.cpp, SD_card.h, Ublox.cpp]
2023-01-09 SW 5.68
    * Analog bat measurement to function()
    * ESP32 time is now local time, min 5 sats visible !!
    * Add check for nav pvt valid flags time&date before setting the time (thanks Peter!)
    * Check for plausible year when GPS time is set (>=2023)
    * Removed timelib.h, only sys.time.h needed
    * Fix time_bug in different screens
    * Add Ubx ID M8(ROM3 necessary,5 byte ID), saved in error.txt
    * Add Ubx ID M10(6 byte ID), saved in error.txt
    * Add Class GPS_NAV_INFO + Evaluation last 16 NAV_SAT msg in log file error.txt
    * Add navDOP msg to ubx file, if nav_Sat is active (for analysing data)
    [ESP32FtpServerJH.cpp, E_paper.h, GPS_data.cpp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]
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2023-01-12 SW5.69
    * SW 5.69
    * Change baudrate for M10 to 38400 bd, #define ALI_M10 in rtos5.h
    * Bugfix for gpy file : MakeTime -> mktime, offset from 1970 -> 1900, month -1 !!!
    * Option for other wake-up GPIO with #define in rtos5.h
    * Add type e-paper to .txt file
    * Some text in e-paper adapted : Mile ->NM, Alf->Alph, Dis->Dist
    [E_paper.h, SD_card.cpp, SD_card.h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]
2023-01-13 Revert "SW5.69"
    This reverts commit c98975f69f6cf88c78dd4c264bc312985d302262.
    [E_paper.h, SD_card.cpp, SD_card.h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]
2023-01-13 SW70
    * Again timebug -> e-paper keyword "now" may not be used for getLocalTime() !!
    * Same issue in SD_card.cpp -> open files !!
    * GPS_SAT_INFO buffer 16 -> 10
    * Set GPS_time @ start logging
    * check for year>2023
    * While waiting for Sats / Min speed : Wifi Off with waiting Sats/Speed on screen
    * Total time in .Txt from start logging
    [E_paper.h]
2023-01-17 SW5.71
    * Again bugfix for time in gpy file (offset year 1970->1900, month->-1)
    * Removed #include timelib.h
    * Removed listing of directorys in webserver
    * Add sortTable() after DOM is loaded : now the files are ordered by date after loading all filenames !
    * Timestamp files with FTP command MLSD is now UTC
    * Add type of ublox to .txt file + e-paper shut down
    [ESP32FtpServerJH.cpp, E_paper.h, OTA_server.h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]
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2023-02-23 SW5.73
    * SW5.73
    * Bugfix name ublox M10 38400bd in off screen
    * Downloading _filename bugfix, no underscore
    * timezone changed from int -> float for partial timezones, drop down menu choice !!
    * Speed screen 5 -> distance always km/h, run -> bat symbol
    * Added auto detection ublox type M8 / M10 and 9600bd/38400 bd
    [E_paper.h, OTA_server.h, SD_card.cpp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]
2023-03-31 SW5.74
    Debouncing reed switch with 200ms @boot
    Shutdown screen 10s -> 5s
    Bat voltage calibration min value 1.7 -> 1.6
    Bugfix GPIO12 screens
    Changed default settings when no config.txt
    Add watchtdog to task0 + task1 separat, Time out = 60 s
    Changed order Wifi screen, so IP is not in the middle anymore
    [E_paper.h, SD_card.h]
2023-04-05 SW5.74
    Check bat voltage@boot, if too low back to sleep. This to prevent a bootloop
    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
    [E_paper.h]
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2023-05-18 SW5.75
    Bugfix time format gpx files
    Added future fly logo (basti)
    Bugfix .txt file M8/M10 serial nr
    Added TROUBLE screen if no ubx message for longer then 2000 ms
    Added SPEED2 screen with giant Font (Simon Design)
    filesizes always in MB
    override watchtdog_task0 when downloading (large) files
    Added SD Free space Mb in Boot screen
    Boot screens changes by Simon, ESP-GPS logo added
    Added actual SW version & Type of e-paper to Firmware page
    [E_paper.h, OTA_server.h, SD_card.cpp]
2023-06-14 SW 5.76
    Sleeptime 3000s -> 21600s
    nav_sat timeout 2000 ms -> 4000 ms
    add 1h to speed screen, setting 9
    bugfix wifiAP screen : name SoftAP
    shutdown screen : Saving your session or Go back to sleep
    Autodetect GPS only once, then saved in EEPROM
    Can be changed over the webserver (configuration), only set AUTODETECT again !
    Added support for the ublox M9 (Beitian BK180), logging@20Hz + 4 gnss simultan
    [E_paper.h, GPS_data.h, OTA_server.h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]
2023-07-06 Fixed: OTA_Server upload page javascript GPS_Data changed stack size from 10000 to 9500 for fitting into 1.5m image Some compiler errors about types
    Changed:
    E_paper>
    -Display unified row heights
    -ESP-Gps logo size to 24x24
    -Moved time, gps and battery for all screens to bottom row infobar.
    Added support to PlatformIO and partially for ESP-IDF (CMakefile.txt),
    thats why Rtos.ino moved to main.cpp
    [ESP32FtpServerJH.cpp, E_paper.h, GPS_data.cpp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]
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2023-07-20 SW 5.77 (AVO PRYKK)
    ### Changes SW5.77 (mainly by avoprykk)
    #### Fixed:
    * OTA_Server firmware upload page javascript.
    * GPS_Data changed BUFFER_SIZE from 10000 to 9500 as for fitting into 1.5M Image partition.
    * Some compiler errors about types.
    #### Changed:
    * E_paper>
    * Display unified row heights macros, changes in screens accordingly
    * ESP-GPS logo size to 24x24
    * Moved time, gps and battery for all screens to bottom row infobar.
    * New screen for GPS initialization.
    main.cpp> Ublox initialization moved after Wifi connections closed.
    #### New:
    * Partial code for OTA autoupload, dev status yet.
    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
    [Definitions.h, ESP_functions.h, E_paper.h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]
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2023-11-09 SW 5.80
    ### Changes SW5.80
    * Extended choice for sample rate : add 4 Hz and 8 Hz
    * extended choices for GNSS
    ** M10 4GNSS : GPS+GLONAS+GALILEO+BEIDOU, max 4Hz or lost points....
    ** M10 3GNSS : GPS+GALILEO+BEIDOU_B1C : 8Hz possible with no lost points (default = GPS+GALILEO+BEIDOU_B1L )
    ** M10 3GNSS : GPS+GALILEO+GLONAS, max 5Hz or lost points....
    ** M10 2GNSS : GPS+GLONAS or GPS+GALILEO : 10Hz possible with no lost points
    * Sample_rate limited in function of GNSS settings (M10)
    * Wifi AP bug fixes
    [ESP32FtpServerJH.cpp, ESP_functions.h, OTA_server.h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]
2024-01-24 SW5.81
    added drop down menu for Sail and Board logos
    added board logos Carbon Art, Thommen, Bic
    added saillogo S2_Maui=11
    gpx.h changes for better fit to the standard (http -> https, indentations, stand alone, contribution from Michael G)
    removed limits for sample-rate
    added warning after upload if the sample-rates are too high
    ShortPush39 50ms->10ms
    [ESP_functions.h, E_paper.h]
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2024-02-11 sw 5.82
    Added local storage if no SD found
    Webserver changes
    Bugfixes
    [Definitions.h, E_paper.h, OTA_server.h]
2024-03-01 SW 5.83
    *Cpu freq when SetupGPS() 240 MHz -> 40 mHz, Current with M10 87 mA -> 57 mA
    * Cpu freq configurable 40, 80, 160 or 240 MHz
    * Warning in webpage "Files" if CPU-freq is not optimal
    * Checksum fail UBX message in error log
    * Voltage battery in infobar
    * First test : 5 Hz -> need 80 MHz, 10 Hz -> need 80 Mhz
    * Add "Giant font ON" in speed screens
    * Moved E_paper task to core 0
    * RxBuffer Serial2 1024 -> 2048
    [Definitions.h, ESP_functions.h, E_paper.h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]
2024-03-01 Corrected for SPEED2 screens and Batteru choice for voltage or percentage in configuration.
    [ESP_functions.h, OTA_server.h, SD_card.h]
2024-05-05 SW5.84
    * new run start only if speed>4m/s
    * Support for daylight saving in several timezones, configurable.
    * Support for 2 SSID (can be used with smartphone hotspot)
    * Bugfix in gpx file : first line start with <<, should be <
    * Bugfix auto-detect gps
    * Auto calibrate -> when charging in deepsleep, with every wake up(1800 s), ADC bat voltage is measured
    * and highest value is stored in eeprom. With full charging, this should be the end voltage of the charge IC TP4056 (4.2 V)
    * cal_bat in config.txt is only for info !!
    * see https://lygte-info.dk/review/Review%20Charger%20TP4056%20UK.html
    * Added bitmaps for FMX, ChallengerSails, Phantom, F4 (contribution Simon)
    [Definitions.h, ESP_functions.h, E_paper.h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]
2024-05-23 SW5.85
    ### Changes SW5.85
    *changed value STARTVALUE_HIGHEST_READ 2500 -> 2300, otherwise out of limit in config !
    *Wifi searches fist for SSID1, then SSID2, if Wakeup is pushed -> AP-mode
    *Wifi screen shows SSID when trying to connect
    *No config.txt -> wifi_search = 10, because connection to ssid2 after 10s
    *Speed screen Simon font bug fixes
    [Definitions.h, ESP_functions.h, E_paper.h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]
2024-05-24 Revert "Merge pull request #31 from Freezer-SD/2sec-stats"
    This reverts commit 8ec8cc027bc22da2827daee671d91202818f8c95, reversing
    changes made to c063a701c3e4aeae5045b8eaa849485b738239e3.
    [ESP_functions.h, E_paper.h, OTA_server.h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]
2024-05-25 SW5.85
    Reset branch to SW5.85
    [Definitions.h, SD_card.cpp, SD_card.h]
2024-07-21 SW5.85
    ###Changes SW5.85
    * changed value STARTVALUE_HIGHEST_READ 2500 -> 2300, otherwise out of limit in config !
    * Wifi searches fist for SSID1, then SSID2, if Wakeup is pushed -> AP-mode
    * Wifi screen shows SSID when trying to connect
    * No config.txt -> wifi_search = 10, because connection to ssid2 after 10s
    * ###Changes SW5.85
    * changed value STARTVALUE_HIGHEST_READ 2500 -> 2300, otherwise out of limit in config !
    * Wifi searches fist for SSID1, then SSID2, if Wakeup is pushed -> AP-mode
    * Wifi screen shows SSID when trying to connect
    * No config.txt -> wifi_search = 10, because connection to ssid2 after 10s
    * Speed screen Simon font bug fixes
    * JSON buffer 1024 -> 1280
    * Watchdog act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
    [Definitions.h, ESP_functions.h, E_paper.h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]
2024-08-11 SW5.87
    Bugfixes for correct timesetting : timezones tz and gpy.h
    [ESP_functions.h, E_paper.h, OTA_server.h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]
2024-10-23 SW5.89
    Added Lisa logos
    Stat_screen 7,8,9 no info-bar, because info-bar overwrites last line....
    Shorten bar_length if actual time is visible
    Added bar length info on the screen (large font on)
    Added speed_screen 7 -> 500m (Weymouth speed week!)
    Added stat_screen 8 -> Best 500m runs + timestamp.
    Added stat_screen A -> Best 2s runs + timestamp
    stat_screen / speed screen choice extended, digits + characters can be used.....
    Bugfix in simon screen : rounding error fix
    [ESP_functions.h, E_paper.h, OTA_server.h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]
2024-12-11 SW5.90beta
    Stat screen 500m / runs bugfix time reading : time 18:6 -> 18:06
    Adapt FIR filter bat reading 0.1 -> 0.02, more consistent measurement
    Auto calibration, full lipo 4.2V -> 4.3 V
    Before Wifi start, min 3.4V
    Override lipo calibration possible, only auto-calibrate with more then 5% too high reading
    Deep sleep current -> 80 µA without SD, with SD 550 µA, this by deleting "hold_gpio_enable()" !!!
    No config.txt -> 10s wifi search
    [Definitions.h, ESP_functions.h, E_paper.h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]
2025-02-02 SW5.91
    * Added 115200 Baud for Beitian Bx122
    * Bugfix for M8@38400 bd
    * Added estimated logtime left (webserver+display). Calculates logtime with actual settings sample-rate, file selection and free space.
    * GPIO 19 Go to sleep pin PULLDOWN.
    * GPIO 21 hold HIGH SIDE SWITCH
    * GPIO2 pulldown in deepsleep, was still floating
    * Added statscreen B , last run, best run, slowest run and average
    [partitions_16MB.csv]
2025-02-17 SW6.00
    * SD in SD_MMC 1bit mode, this is the hardware SDIO bus from the ESP32. Only with dedicated pins possible.
    * Proposal from Alhop for the SD NAND cards : SD_MMC 1 bit instead SD over SPI
    * Pullup needed on pin 2 before begin.SD_MMC needed for some cards
    * Pullup in deepsleep on pin 2 for minimize leakage current SD cards
    * Bugfix for GPIO 12,19 and 39 init with pulldown/pullup
    [ESP32FtpServerJH.cpp, ESP_functions.h, E_paper.h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]
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2025-05-29 SW6.00
    ###Changes SW6.00
    * M10 set permanent to high nav rate possible, at the cost of a higher current draw (+5mA...) (Irreversible !)
    * Added SD_MMC write/read speed, file test.txt of 1MB is used for this
    * Speed measuring SD card, file test.txt 1MB used for measurement, results saved in file.txt
    * Added shutdown_voltage to config : if set to 0, you can force a powercycle by draining the lipo !
    * Added warning in webserver as shutdown_voltage in config < 3.0 V
    * min cpu freq = 80MHz, is needed for SD_MMC
    * boot @ 240 MHz, as SD_MMC need min 80 MHz
    * As the sd card only wil reset afte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
    [partitions.csv, partitions_16MB.csv, partitions_4MB.csv]
2025-08-06 SW6.01
    * Added sign to Dist point to line ()
    * Added GPIO19 for switch to AP-mode
    * New run detection after stop delayed until speed > 4 m/s
    * Statscreens can be switched by GPIO39 short push if Stat screen time is set to 0. No speed screen choice then with GPIO39 short push !
    [Definitions.h, ESP_functions.h, E_paper.h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]
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2025-09-15 SW6.01a
    Bugfix calculation AVG 5*10s !
    [ESP_functions.h, E_paper.h, GPS_data.cpp]
2025-09-27 SW6.01c
    Added E-paper type to SW version
    Bugfix speedscreen 6, max_display_speed
    Add speedscreen A, with CM = 2s max run and TM = 2s max session
    Logtime left prevent divide by 0 is al logfiles are switched off
    [ESP_functions.h, E_paper.h, GPS_data.cpp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]
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2026-07-30 SW6.05delta
    ### Changes SW 6.05delta
    * settings M10 added tot .txt file
    * full power mode in the config
    * Added setting M10 minimal elevation satellite above horizon, 5 - 25 degrees
    * Stat-screen D 5-9 track speed, update Top_5()
    * Stat-screen E Ranking Nautical mile screen
    * Stat-screen F Ranking 100m screen
    * track_speed Start -> finish now with exact doppler - distance
    * added projected doppler speed to track speed (only in stat screen now)
    * json buffer now 2048 bytes (was 1536)
    * Screen orientation now in config, had to update GXDEM0213B74 lib, and bugfix for screen offset (added VISIBLE_WIDTH 122)
    ### Changes SW 6.05beta
    * Added max nr of satellites in config (motion has a fix limit o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
    [partitions.csv]
2026-08-30 SW 6.05g
    ### Changes SW 6.05g
    * bugfix screen 6 / shut down screen
    * Added maxSVS in config, to limit nr of sats in nav solution. This for "lost points" prevention
    * GPS nerd settings button in configuration webpageto hide all detailed gps settings
    * p1/p2 data type in json is now string, so all digits stay unchanged
    * check for string type p1/p2, other wise panic when still double type !!!
    * Auto track setting when p1/p2 is zero in the config : first 500m run with speed min 5 m/s after 600 m run distance
    * Stat-screen D 5-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
    [ESP_functions.h, OTA_server.h, Rtos6.ino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]
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2026-10-08 SW7.0c and SW6.06
    ### Changes SW 7.0c
    * Added actual partition size in firmware webpage
    * Bugfix naming &.gpy -> $.gpy
    * Bugfix calibration bat in configuration (was stuck on 1.83)
    * Watchdog now default functions
    * infobar removed vor statscreen F and G (top5 100m / NM)
    [Definitions.h, ESP_functions.h, E_paper.h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]
2026-10-15 Auto-upload: wait 90 s for the response and stop on a stalled write
    speedsurf.app saves the session before it answers (metrics, spot, wind,
    tide), which takes 5-60 s. With a 10 s wait the ESP reported a time-out
    and sent the file again; the server then answered 'already uploaded'.
    client.write() results were not checked, so a stalled write (seen on a
    phone hotspot) went unnoticed while Content-Length promised the whole
    file. The upload now stops and logs how many bytes went out.
2026-10-15 Wi-Fi: print why the connection drops, no modem sleep during an upload
    Paco's 7.0f log over his phone hotspot: the Wi-Fi link drops a few
    seconds into the upload (STA_DISCONNECTED before the write fails, about
    8 s for 3 KB). The reason code says which side let go; the core only
    logs it at Core Debug Level Warning, so print it in every build.
    Modem sleep is the usual first suspect with Android hotspots: off while
    an upload runs, back on after.
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2026-10-30 SW7.1beta
    ### Changes SW 7.1beta
    * Date and time format in file names now with - (ESP-Discussions)
    * Function Stats_4lines() and Stats_2s_3lines() now layout Message and float fix decimal point (ESP-Discussions)
    * Stat4 screen : smaller font for better layout (ESP-Discussions)
    * Removed s1,s10,a500 instances (not used anymore)
    * Minimal elevation sats in config now 0°, max 15°
    * Set read-out ISR hardware buffer Serial2 to max 63 bytes (default 120 bytes, buffer = 128 bytes)
    * CPU clock warning 5 Hz < 80MHz, 10 Hz < 160 MHz, but it looks that even 80 MHz & 10 Hz will work without lost points.
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
